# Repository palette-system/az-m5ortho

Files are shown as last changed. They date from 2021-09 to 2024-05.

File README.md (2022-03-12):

# AZ-M5ortho

## 販売サイト

- [BOOTH](https://booth.pm/ja/items/3329196)
- [遊舎工房](https://shop.yushakobo.jp/collections/keyboard/products/2949)

## メディア

【記事】AKIBA PC Hotline 様<br>
https://akiba-pc.watch.impress.co.jp/docs/news/news/1359054.html
<br><br>

【記事】fabcross 様<br>
https://fabcross.jp/news/2021/20211019_yusyakobo_m5stackkeyboard_azm5ortho.html
<br><br>

【記事】kuriharaのブログ 様<br>
https://kurihara.hatenadiary.jp/entry/2021/10/16/202059
<br><br>

【記事】ErgoMechKeyboards 様<br>
https://www.reddit.com/r/ErgoMechKeyboards/comments/qkbzg8/azm5ortho_wireless_ortho_touchpad_in_the_middle/
<br><br>

【記事】protopedia 投稿記事<br>
https://protopedia.net/prototype/2487
<br><br>

【記事】M5Stack Japan Creativity Contest 2021<br>
https://protopedia.net/event/22
<br><br>

【記事】いとうひよこ 様<br>
https://note.com/tsubuan_145/n/n36ca745d76a6
<br><br>

## ドキュメント
  
- [入っている物](/docs/azm5ortho/builtin_parts/)
- [作成マニュアル](/docs/azm5ortho/build_guide/)
- [初期設定マニュアル](/docs/azm5ortho/Initial_setting/)
- [液晶画面設定メニュー](/docs/azm5ortho/moniter_setting/)
- [WiFi設定メニュー](/docs/wifi_setting/)
- [REMAP設定](/docs/azm5ortho/remap_setting/)
- [M5StackCore2 を購入時の状態に戻す](https://w-tori.net/wp/m5stack-core2-reset/)
<br><br>

## デフォルトキーマップ

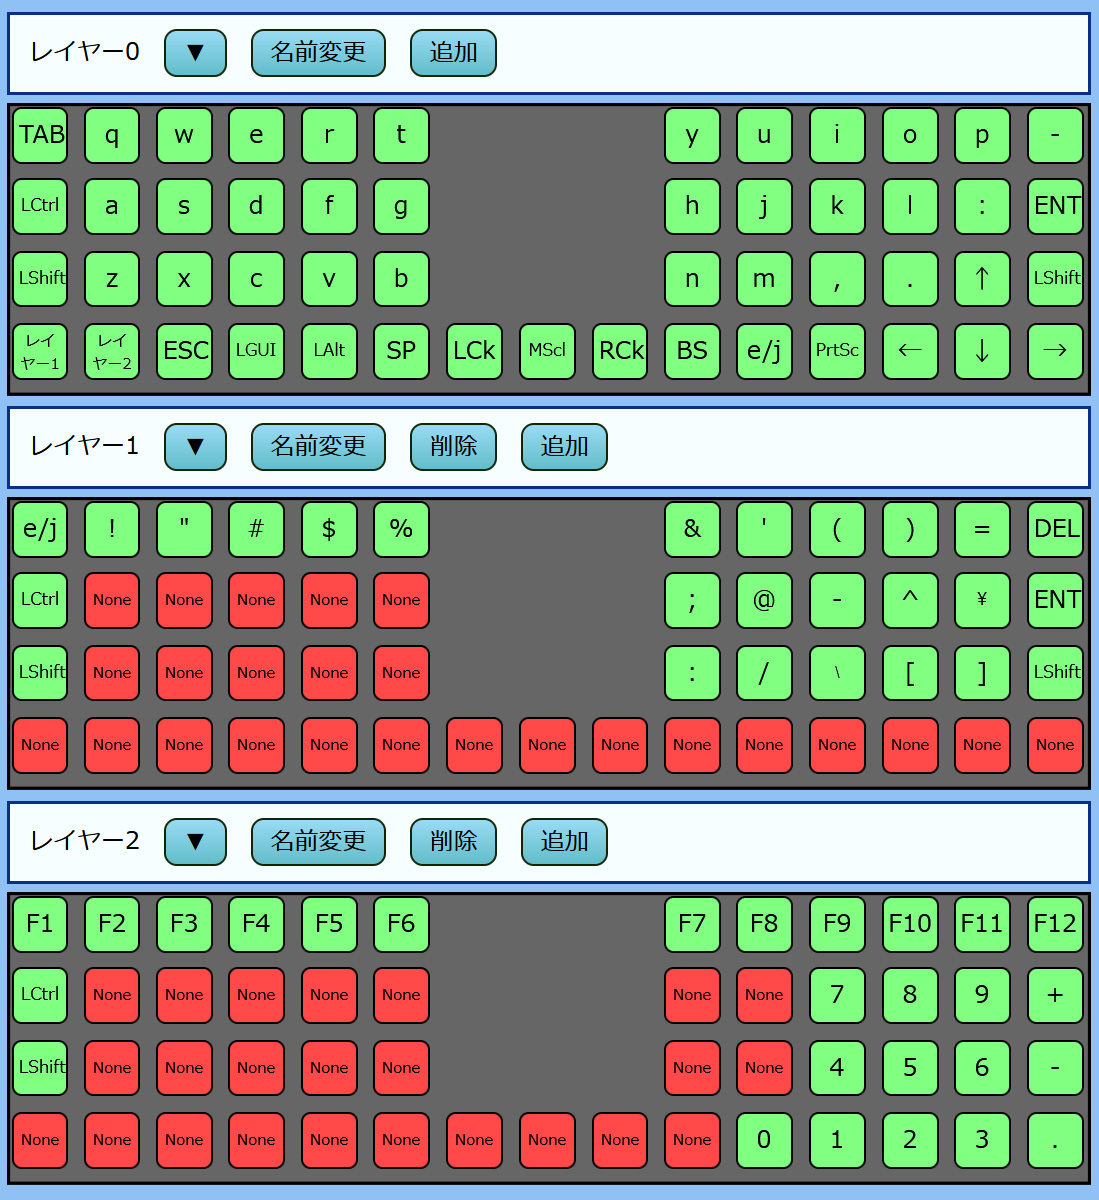
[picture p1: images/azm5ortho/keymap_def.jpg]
デフォルトキーマップ


## M5Stack Japan Creativity Contest 2021 3位入賞

[M5Stack Japan Creativity Contest 2021](https://protopedia.net/event/22)

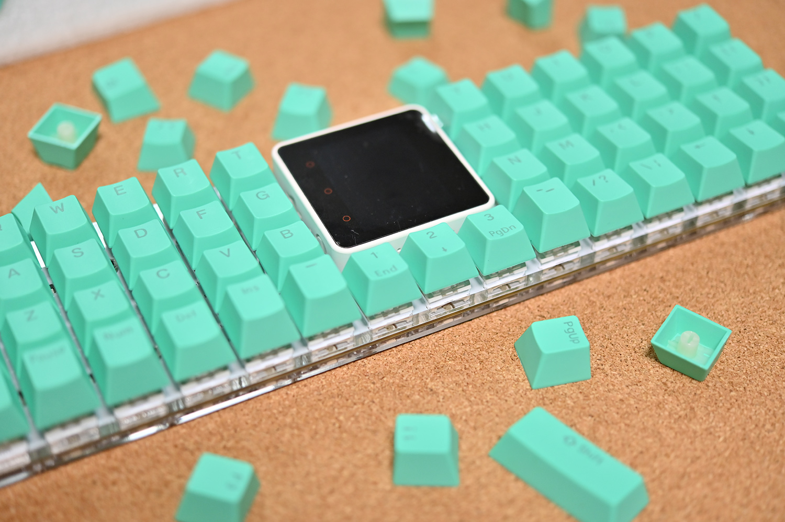
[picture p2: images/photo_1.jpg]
写真1

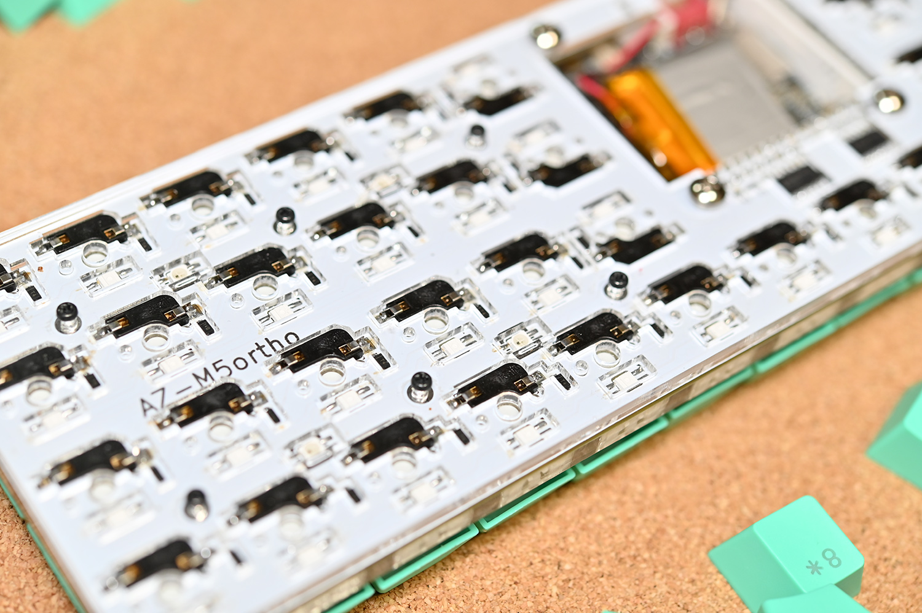
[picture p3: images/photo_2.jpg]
写真2

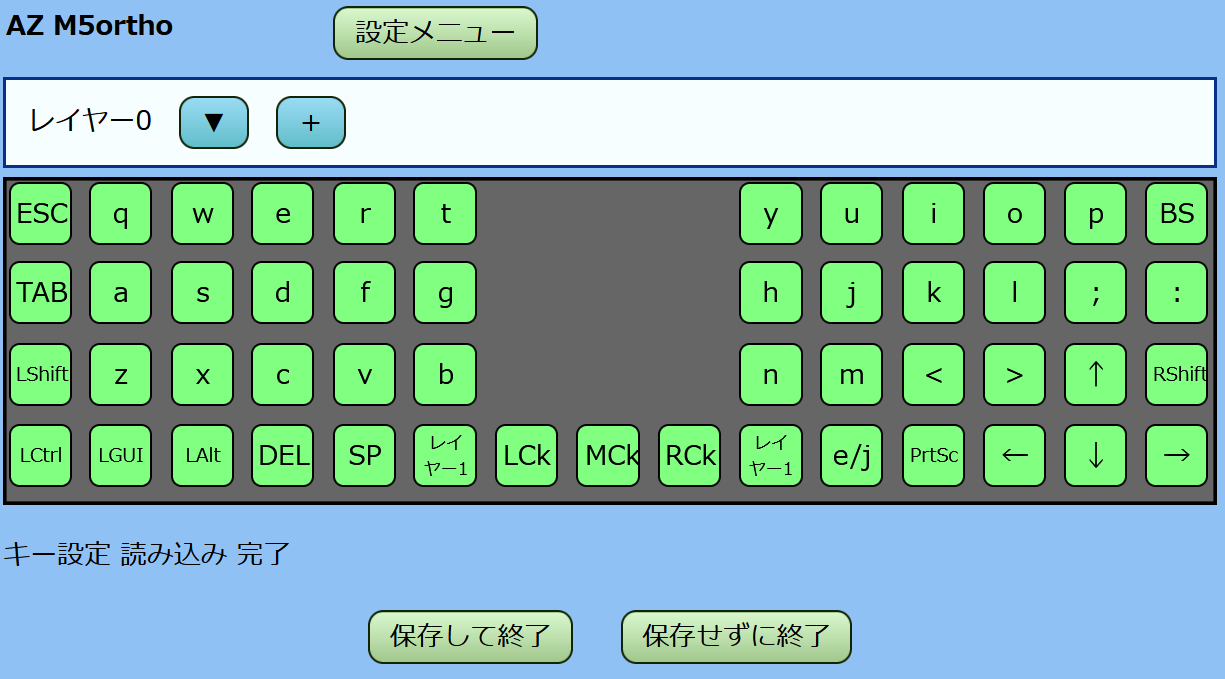
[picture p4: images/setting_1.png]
写真3

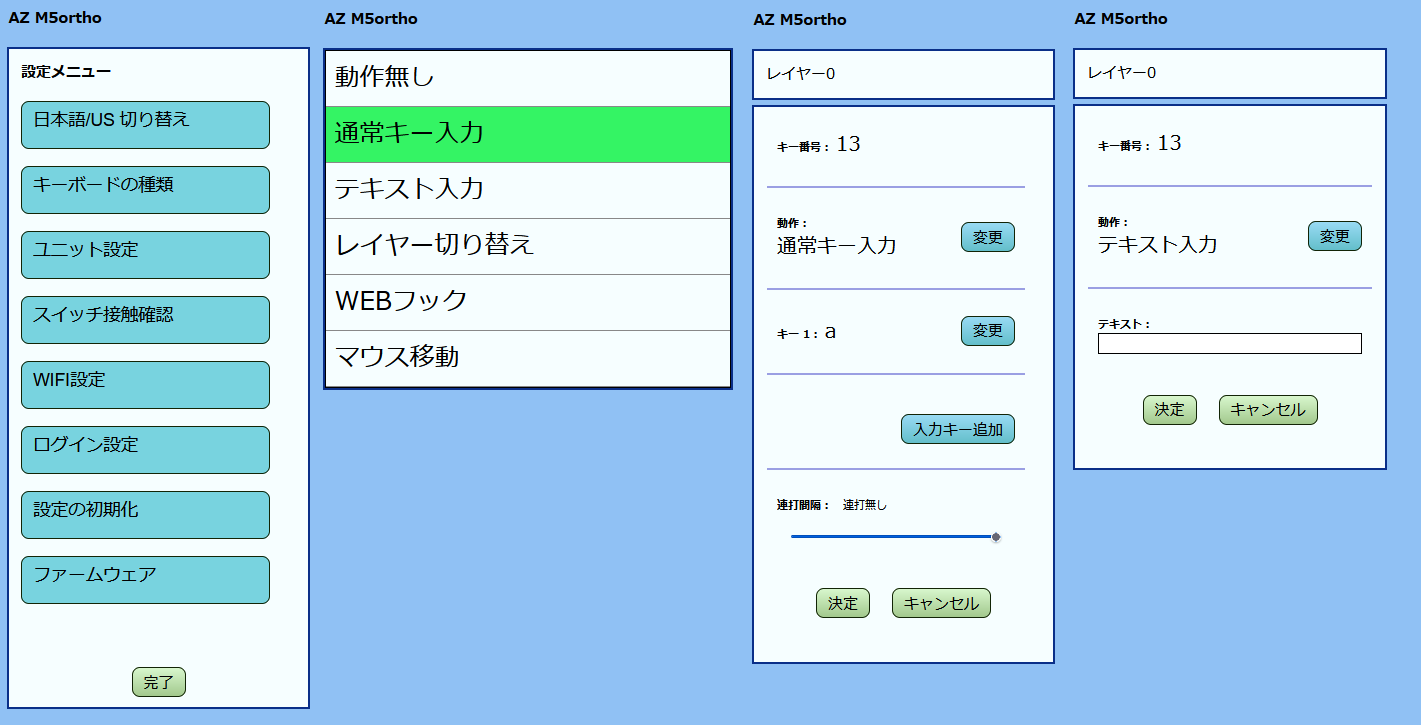
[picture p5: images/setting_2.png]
写真4

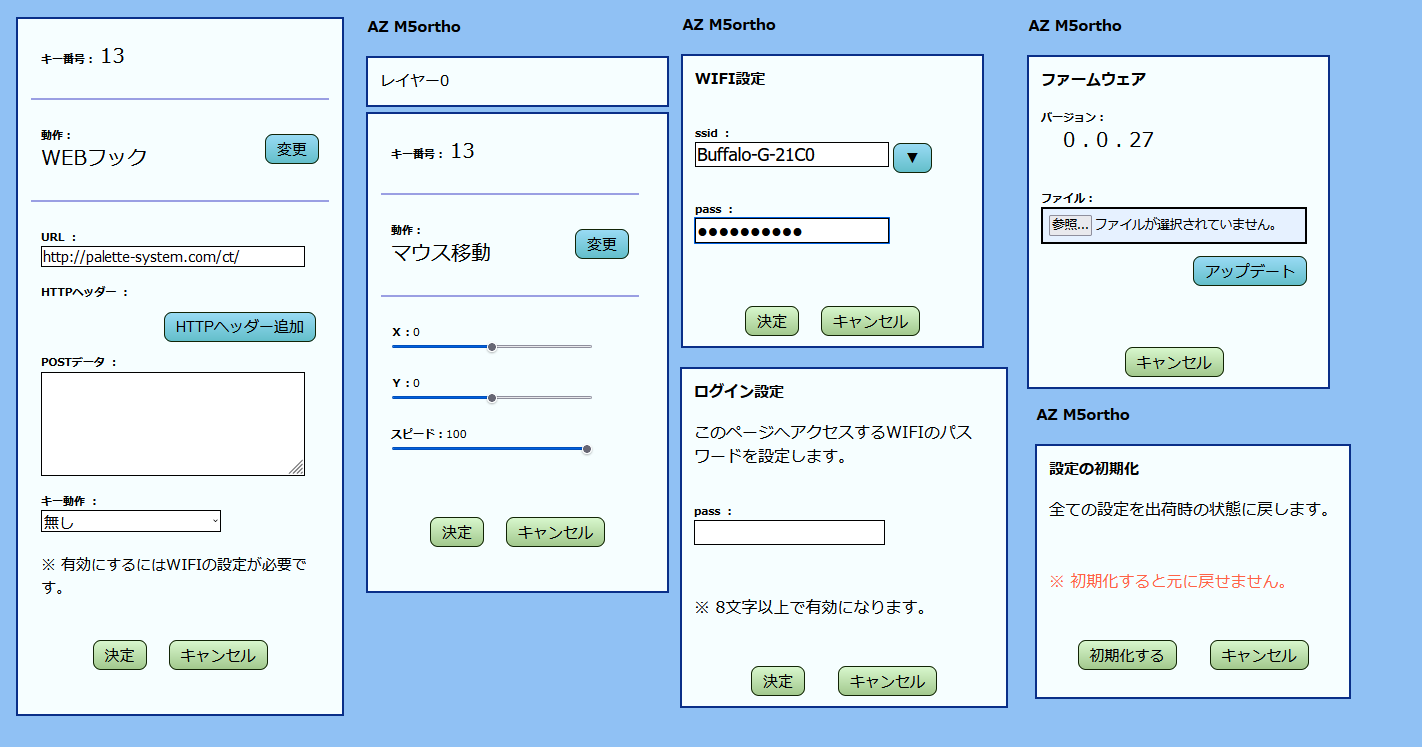
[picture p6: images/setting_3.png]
写真5


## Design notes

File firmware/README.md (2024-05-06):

# AZ-M5ortho ファームウェア
AZ-M5ortho で使用しているファームウェアソースです。<br>
こちらのソースは個人で利用する場合には自由にご利用いただいて大丈夫です。<br>
二次配布については非営利であれば著作権表示をして頂ければご利用して頂いて大丈夫です。<br>

<br><br>

ライセンス：　CC BY-NC-SA 4.0

<br><br>

## 対応商品

- えむごっち
- AZ-M5ortho

## 開発環境

- Arduino 2.3.2

　インストール手順<br>
　https://raspberrypi.mongonta.com/howto-start-m5stack-core2arduinoide/

■ボードマネージャー
- M5Stack 2.1.1

■ライブラリ
- M5Core2 0.1.9
- ESP_OTA 0.2.0
- NimBLE-Arduino 1.4.1
- ArduinoJson 7.0.4
- lv_arduino 3.0.1
- Adafruit NeoPixel 1.12.1
- Adafruit MCP23017 Arduino Library 2.3.2
- ESP8266Audio 1.9.7
- M5Stack 0.4.1
<br>
※ lv_arduino のライブラリインストール後 https://github.com/palette-system/az-m5ortho/tree/main/firmware/lv_arduino のファイルを インストールしたlv_arduinoのディレクトリにコピーして下さい。
<br>
※ 使用フォント　http://www.fontna.com/blog/1226/
<br>　　　LogoTypeGothic ロゴたいぷゴシック 07LogoTypeGothic7.ttf
<br>
※ フォントコンバーター： https://lvgl.io/tools/fontconverter
<br>
※ コンバート時に指定した文字： https://github.com/palette-system/az-m5ortho/blob/main/firmware/lv_arduino/enable_text.txt
<br><br>

## 書込み時のボード設定

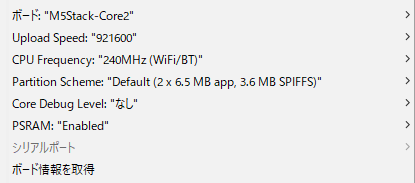
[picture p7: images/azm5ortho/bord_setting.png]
ボード設定


## こちらのツールを使用させて頂いています

- [PROGMEM作蔵さん](https://hello-world.blog.ss-blog.jp/2016-10-16)

## こちらの素材を使用させて頂いています

- [効果音ラボ](https://soundeffect-lab.info/)

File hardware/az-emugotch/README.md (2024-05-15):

# えむごっち

## PCBデータ
[PCBデータ](/hardware/az-emugotch/kicad/)

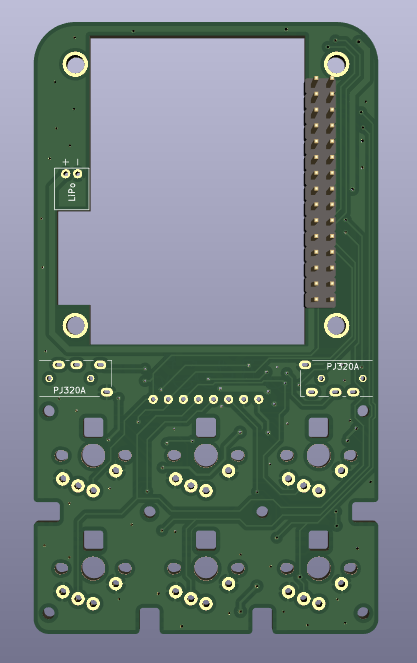
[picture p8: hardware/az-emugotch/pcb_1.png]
表

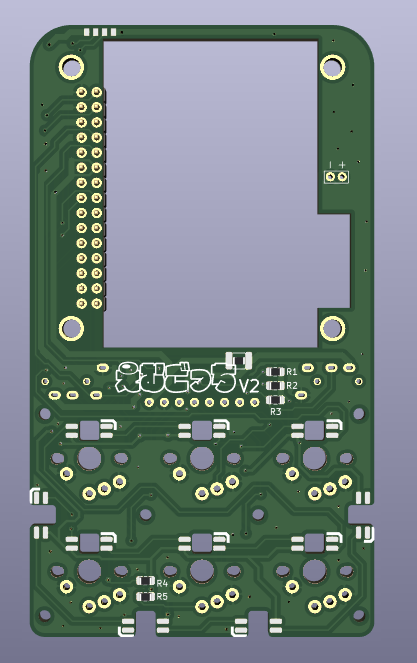
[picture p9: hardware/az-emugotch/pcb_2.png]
裏


## プレートデータ
[プレートデータ](/hardware/az-emugotch/plate/)

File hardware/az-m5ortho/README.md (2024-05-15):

# AZ-M5ortho 

## PCBデータ
[PCBデータ](/hardware/az-m5ortho/kicad/)

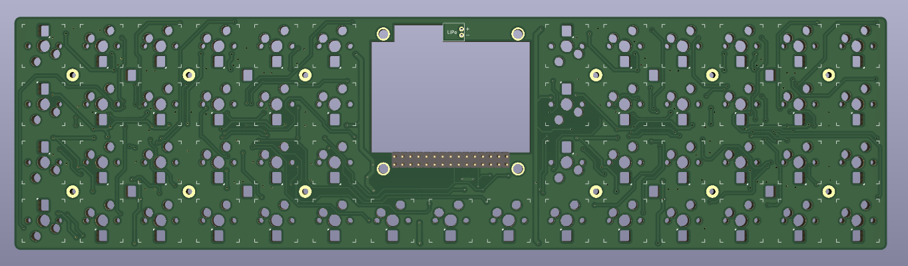
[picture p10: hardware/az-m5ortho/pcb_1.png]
表

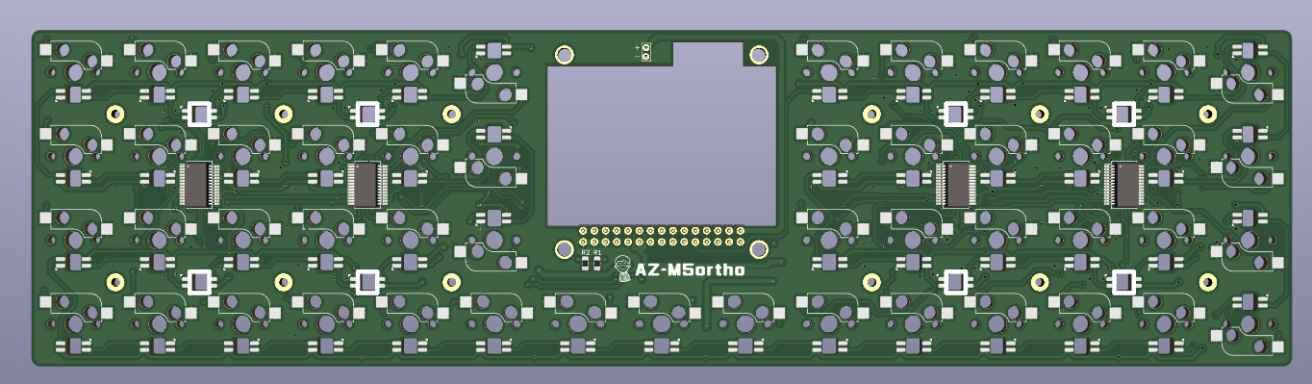
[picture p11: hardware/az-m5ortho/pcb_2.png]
裏


## プレートデータ
[プレートデータ](/hardware/az-m5ortho/plate/)

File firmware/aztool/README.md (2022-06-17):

# 設定ツール

使い方

- M5StackCore2のドライバ　CP2104 Driver　のインストール

　　　　https://shop.m5stack.com/pages/download

- このリポジトリをクローンする

- このディレクトリにある　writer.html　を Chrome で開いて　M5StackCore2　にツール対応のファームウェアを書き込む

　　　※　M5StackCore2とはUSBで接続する

- M5StackCore2とBluetoothのペアリングをする

　　　※　ペアリング済みだった人はペアリング設定を削除してもう一度ペアリングしなおす

- https://palette-system.github.io/aztool/ 　を　Chrome　で開いて設定ツールを使う

# オプションを追加する流れ

- M5StackCore2の電源が入ってない状態でオプションになる基板をTRRSで接続する

- M5StackCore2の電源を入れる

- 設定ツールを開いて「オプション設定」→「オプション追加」からオプションを追加する

- 追加が終わるとM5StackCore2の再起動をして設定画面から追い出されるので、再起動が終わったらまた設定画面から接続する。

　　※　再接続する時は一度ページをリロードした方が安全（なんか前のキャッシュが残ってたりしてて時々変な動きする時がある）

- 「キーマップ設定」を開くと登録したオプションが表示されていて、キー設定が出来る

- キー設定が終わったら「保存して再起動」すると設定した内容が保存されて使えるようになってる

# おまけ

「設定JSON編集」で設定に使用しているJSONを直接操作できる。

VID/PID、I2Cのピン、キーボードのピンなどキーボードで設定してる内容はだいたいこのJSONで設定してます。

| キー | 内容 |
| --- | --- |
| ap.pass | 設定モード(WIFI)で起動した時のWIFIに接続するパスワード |
| wifi | M5StackCore2がWIFIにアクセスするためのAPとパスワード |
| vendorId<br>productId | ベンダーID<br>プロジェクトID |
| rgb_pin<br>rgb_len | NeoPixcell へ接続してるピン<br>何個接続してるか |
| led_num<br>key_matrix<br>matrix_row<br>matrix_col | NeoPixcell 表示に使う用の設定 |
| disp_rotation | 画面の向き |
| keyboard_name | キーボード名 |
| keyboard_type | キーボードの種類コード<br>この値で今どのキーボードとして動いてるか判定 |
| keyboard_pin | 本体のキースイッチに設定しているピン<br>direct - GPIOから直にスイッチ<br>touch - 未使用<br>ioxp - エキスパンダのアドレス(全てdirect) |
| ioxp_pin | I2C接続するピン |
| default_layer | キーボード起動時のレイヤーの番号 |
| layers | キー入力の設定、キー名がレイヤーID |
| layers[n].name | レイヤーの名前 |
| layers[n].keys | レイヤーに登録されているキー設定<br>キー名がキーのID |
| layers[n].keys[k].press | キーが押された時の動作 |
| layers[n].keys[k].press.action_type | 動作のタイプ |
| layers[n].keys[k].press.key | 送信するHIDコード(５個まで同時押し可) |
| option_set | 付けているオプション設定(AZ-Macro用) |
| i2c_option | 設定したI2Cオプションの設定 |
| i2c_option[n].id | オプションの識別番号 |
| i2c_option[n].type | オプションの種類<br>今は 1:エキスパンダ のみ |
| i2c_option[n].enable | オプションが有効かどうか（無効だと入力しても反応しない） |
| i2c_option[n].ioxp | オプションで使用するエキスパンダ(複数)<br>と、エキスパンダのピン設定 |
| i2c_option[n].map_start | キー設定のIDとマッピング開始する番号 |
| i2c_option[n].map | エキスパンダの入力データの何番目がキーになるかのマッピング |
| layout | キーマップ設定でキー配列をドラッグで移動した表示位置 |

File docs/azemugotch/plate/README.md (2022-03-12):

# えむごっち プレートデータ

このディレクトリにあるデータがえむごっちで利用するアクリルプレートのデータです。

- emugotch_middle (3mm)
- emugotch_pcb_bottom (2mm)
- emugotch_pcb_top (5mm)
- emugotch_top_and_bottom (3mm)

# ライセンス

## 使用許諾

- 個人利用に限り自由に使用して頂いて構わないです。

## 再許諾

- このデータを加工して作成したデータも、こちらのライセンスを継承していれば公開しても構わないです。
- 公開時はパレットシステムの名前とこのページへのリンクをどこかへ表記する事。

## 禁止事項

- このデータを使用して作成したいかなる物でも(物理、データ問わず)利用して利益を得てはならない。
- このデータを加工して他の著作権物を侵害するデータの作成、および配布を禁止します。

## 保証及び責任の制限

- このデータを利用して発生したいかなる損害においても損害賠償責任を負いません。

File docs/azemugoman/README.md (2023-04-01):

# えむごまん

## 入っている物

- えむごまん基板　×　１
- バッテリー用PHコネクタ　×　１
- TRRSジャック　×　２
- 六角レンチ　×　１
- ピンヘッダ(2×20)　×　１
- RGBLED　×　１０
- 基板固定用M2×8ｍｍネジ　×　４
- えむごまんボディ　×　１

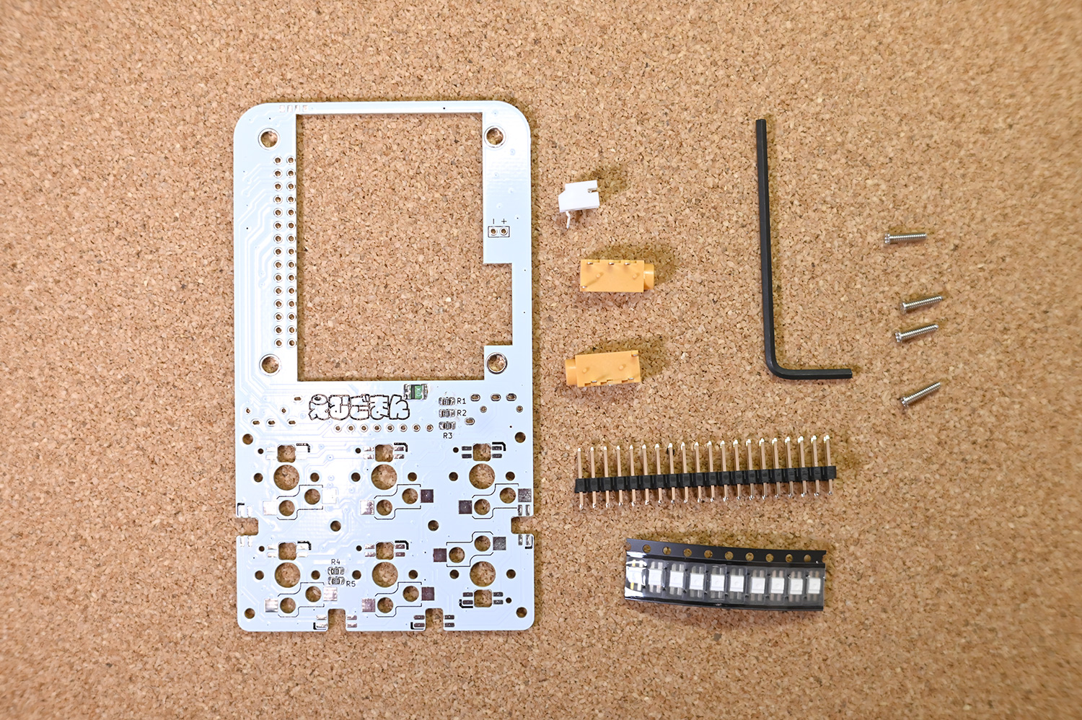
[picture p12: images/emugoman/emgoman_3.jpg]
build_parts

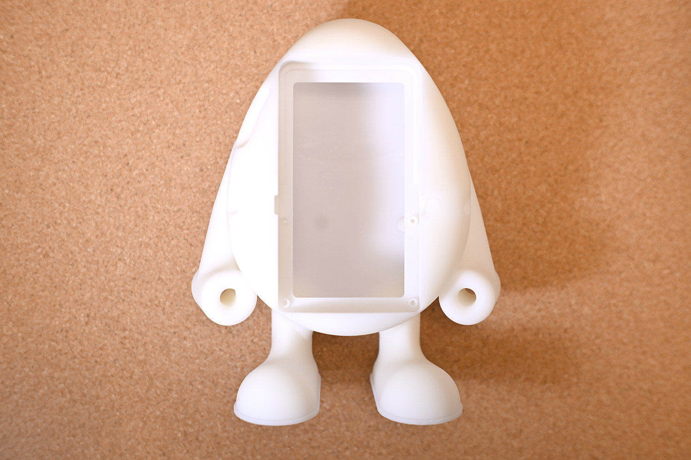
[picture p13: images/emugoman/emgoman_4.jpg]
build_body


## 別途必要

- M5StackCore2　×　１
- Chocソケット　×　６
- Chocスイッチ　×　６（V1、V2両方対応）
- キーキャップ　×　６

## 組み立て手順

はんだ付けやファームウェアの書き込みはえむごっちのマニュアルを参考にして下さい。

<a href="/docs/azemugotch/build_guide">えむごっち　組み立て方</a><br>
<a href="/docs/azm5ortho/Initial_setting">えむごっち　ファームウェア書込み</a><br>

参考用写真

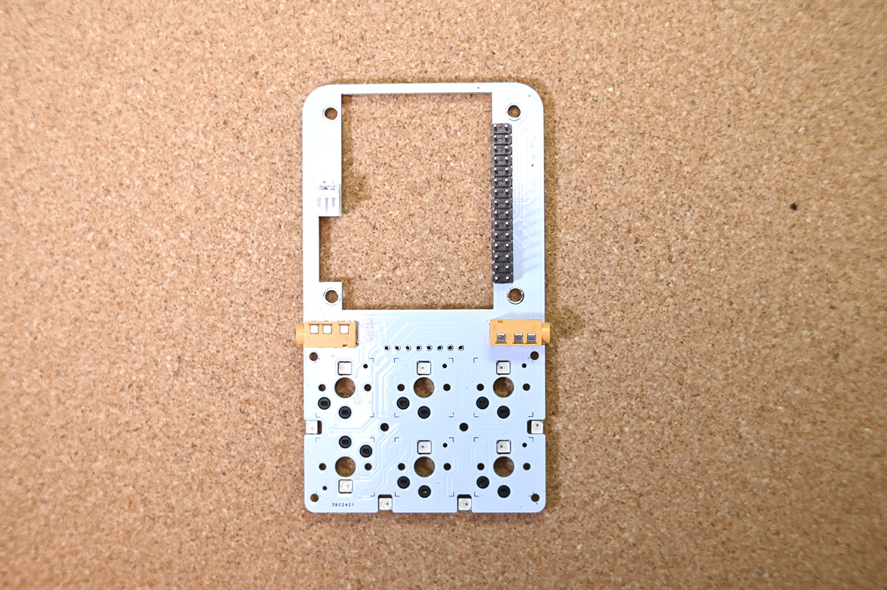
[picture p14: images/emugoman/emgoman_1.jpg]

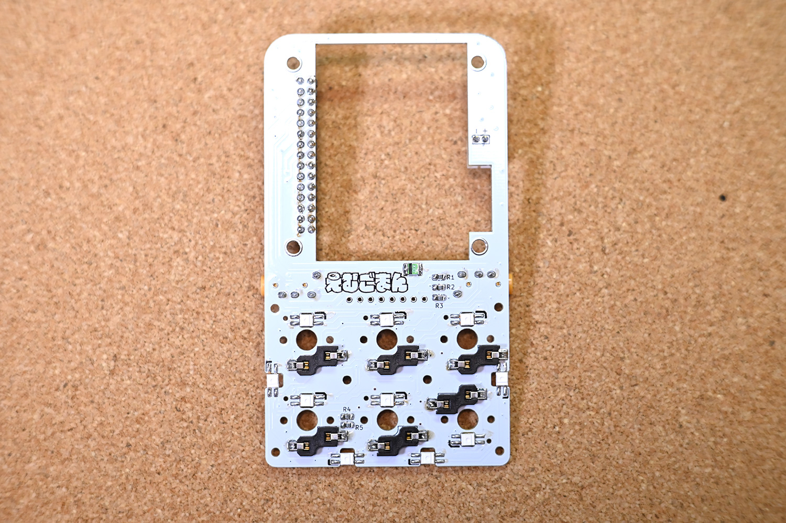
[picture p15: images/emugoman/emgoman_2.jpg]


はんだ付けが完了したらM2ネジ4本を使用してえむごまんボディに基板を固定して、スイッチをはめ込んで下さい。

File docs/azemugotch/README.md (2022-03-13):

# えむごっち

## 販売サイト

- [BOOTH](https://booth.pm/ja/items/3696255)

## メディア

【記事】へりかる 様<br>
https://helical-engineer.com/keyboard-emugotch/
<br><br>

## ドキュメント
  
- [入っている物](/docs/azemugotch/builtin_parts/)
- [作成マニュアル](/docs/azemugotch/build_guide/)
- [初期設定マニュアル](/docs/azm5ortho/Initial_setting/)
- [液晶画面設定メニュー](/docs/azm5ortho/moniter_setting/)
- [WiFi設定メニュー](/docs/wifi_setting/)
- [登録用のWAVファイル作成方法](/docs/azemugotch/create_wav/)
- [回路図](/images/emugotch/emugotch_kairo.png)
- [ファームウェア](/firmware/)
- [アクリルプレートのデータ](/docs/azemugotch/plate/)
- [M5StackCore2 を購入時の状態に戻す](https://w-tori.net/wp/m5stack-core2-reset/)
<br><br>

## 説明

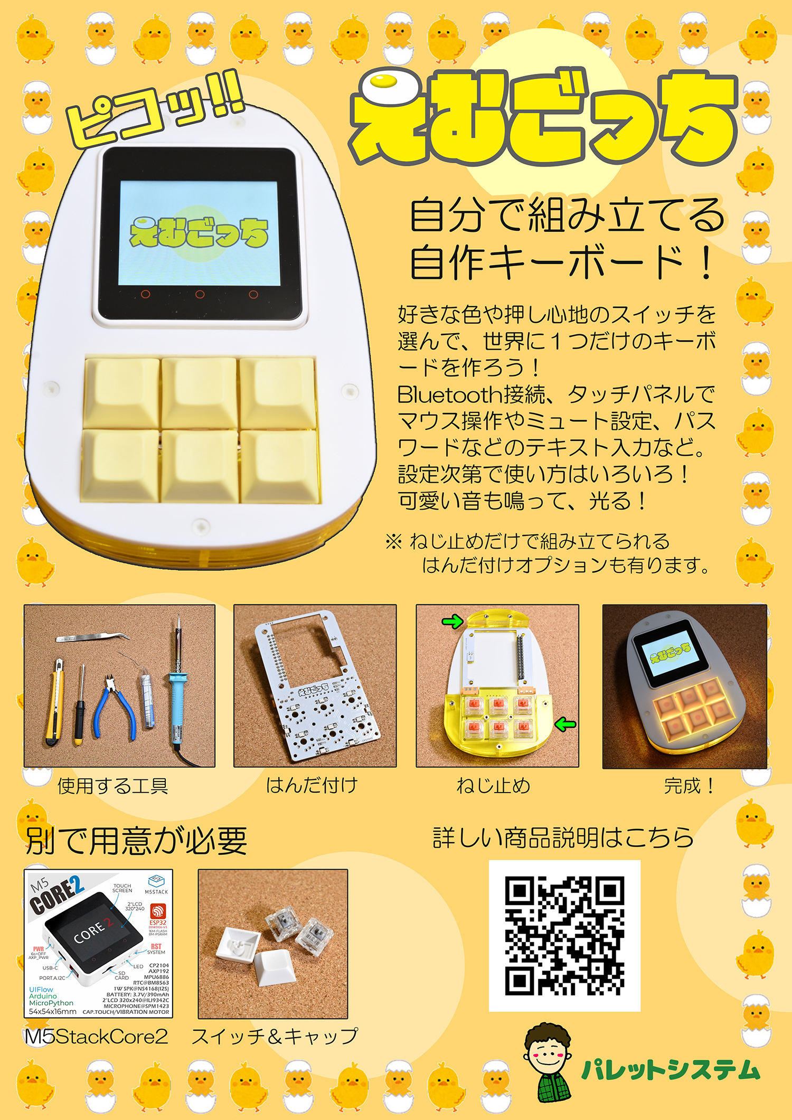
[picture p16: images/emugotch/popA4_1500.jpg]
pop

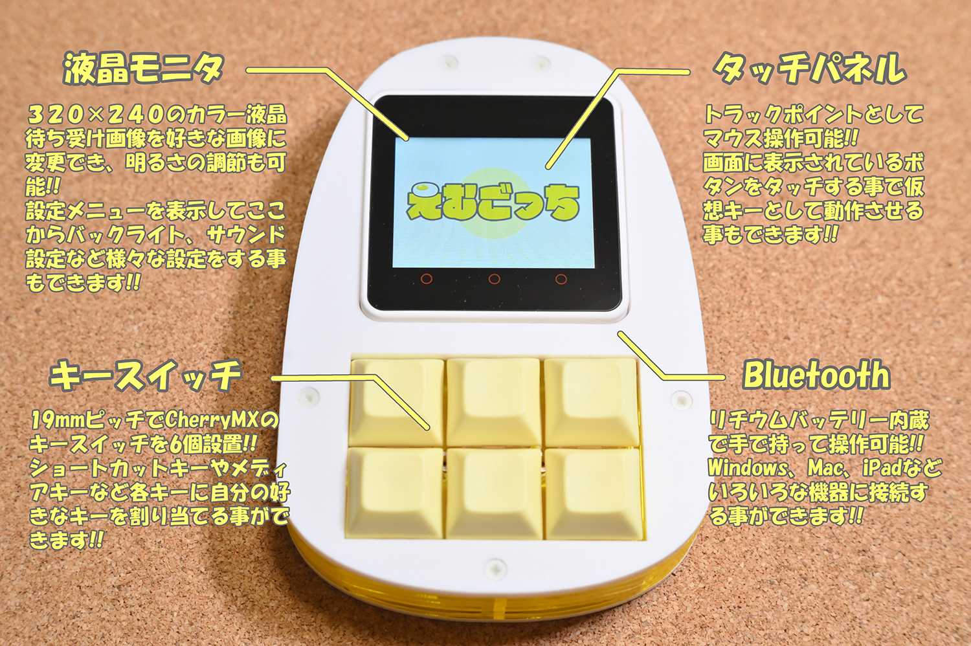
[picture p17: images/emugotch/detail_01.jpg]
説明1

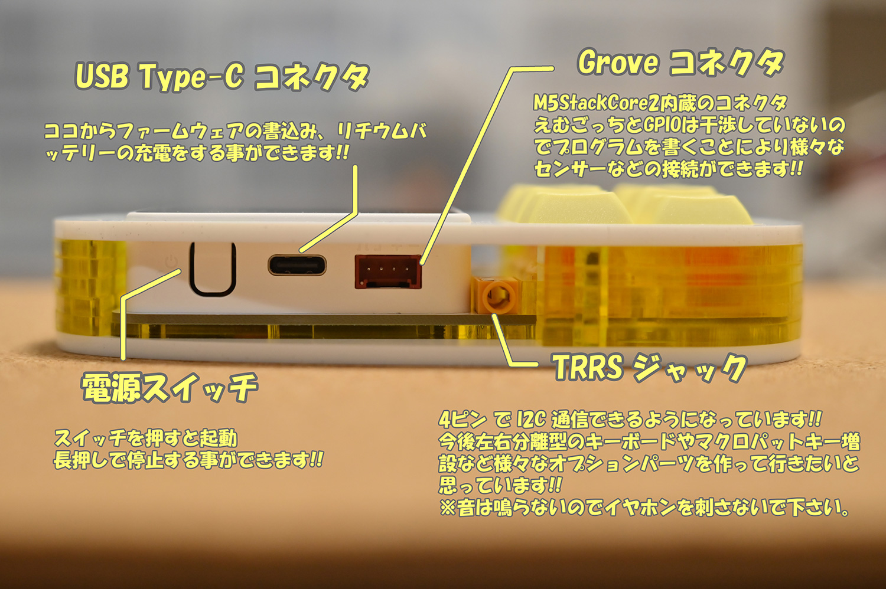
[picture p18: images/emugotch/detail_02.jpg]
説明2

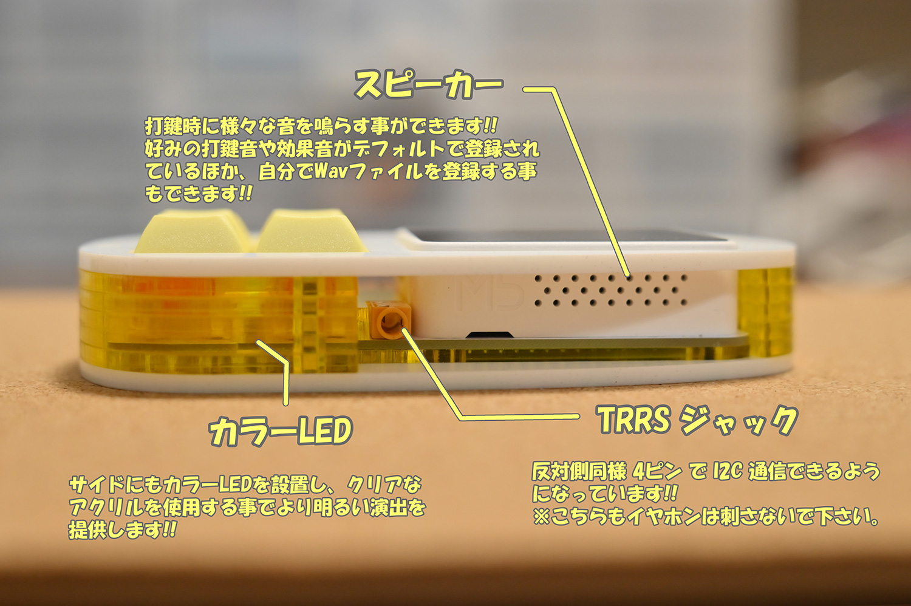
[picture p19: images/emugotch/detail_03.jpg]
説明3


## 写真

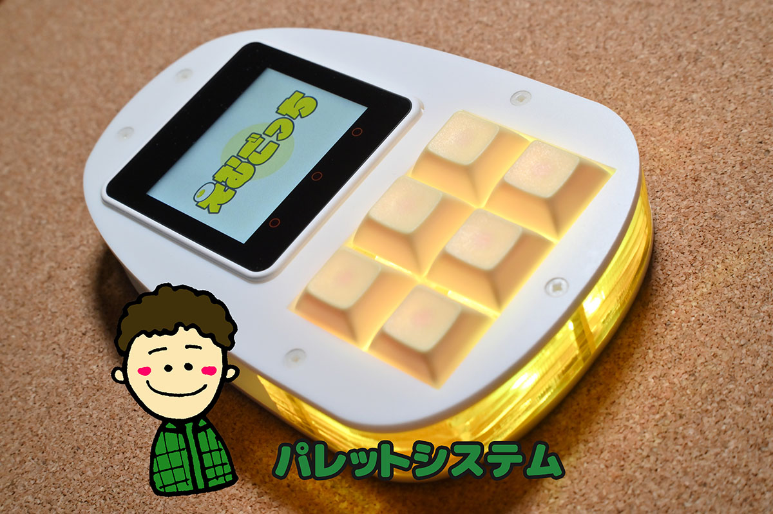
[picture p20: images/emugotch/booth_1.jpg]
写真1

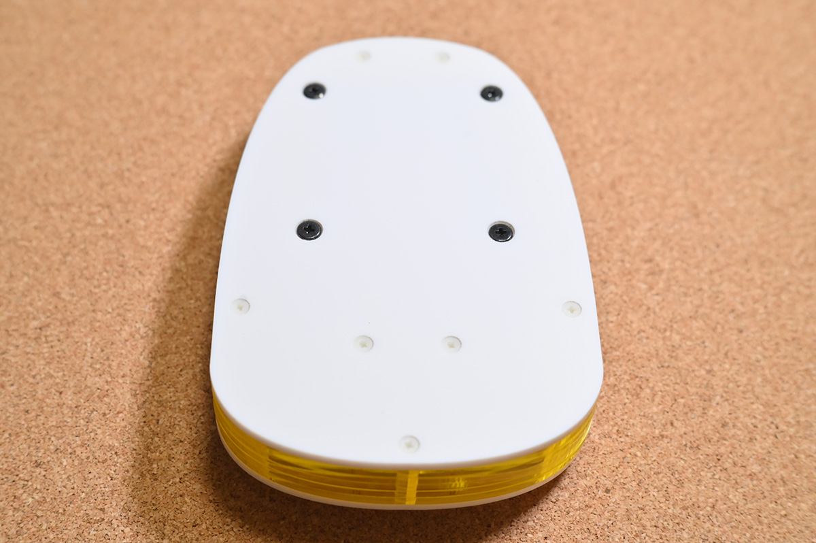
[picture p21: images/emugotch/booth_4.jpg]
写真2

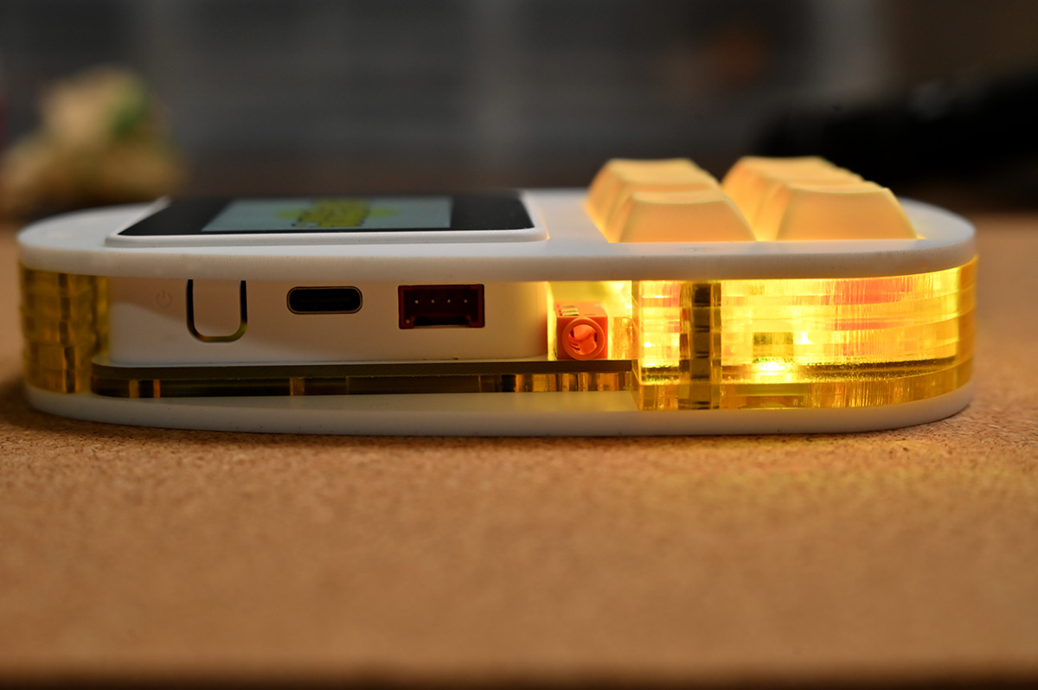
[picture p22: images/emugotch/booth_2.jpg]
写真3

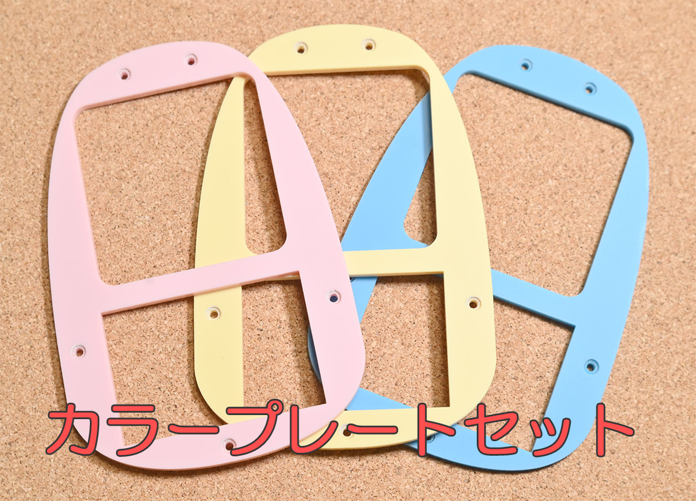
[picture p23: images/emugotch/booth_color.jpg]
写真4

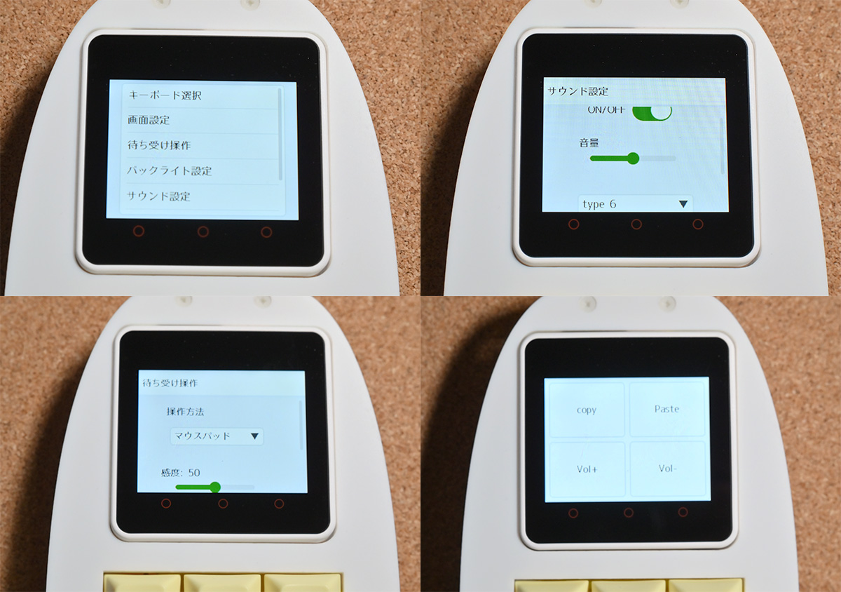
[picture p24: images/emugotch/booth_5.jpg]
写真5

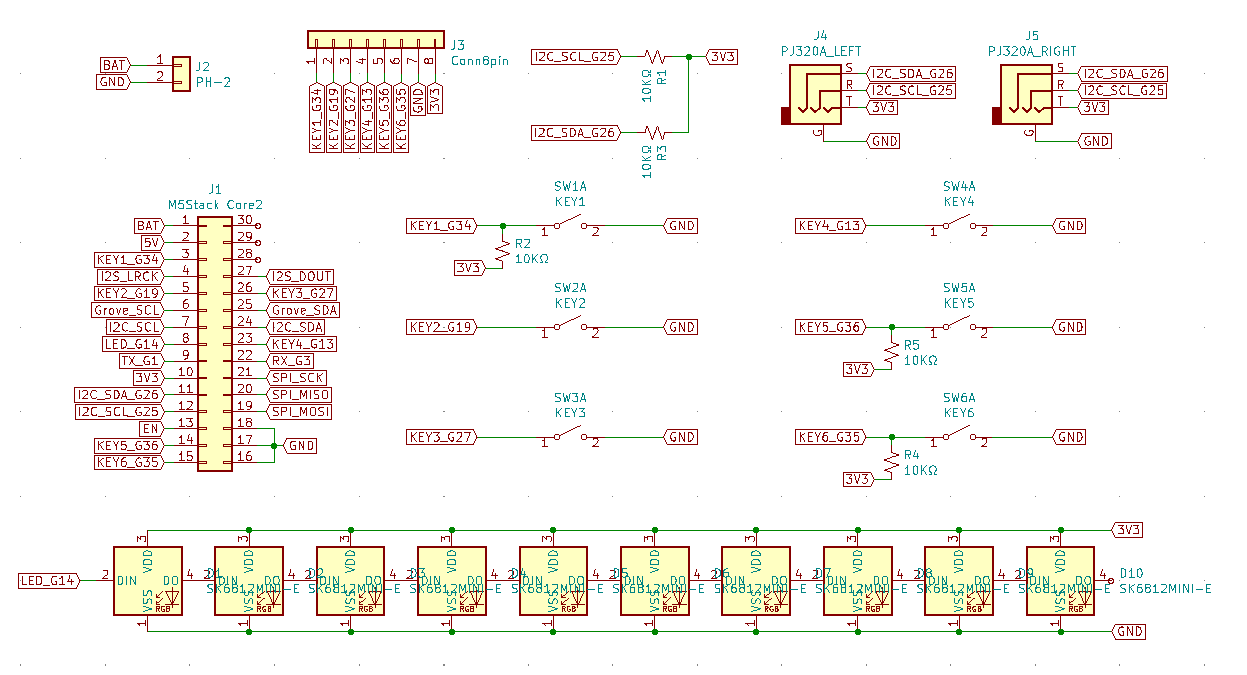
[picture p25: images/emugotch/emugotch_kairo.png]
写真6


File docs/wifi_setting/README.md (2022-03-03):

# Wifi 設定メニュー

<br><br>

## 設定画面の開き方
<table>
  <tr>
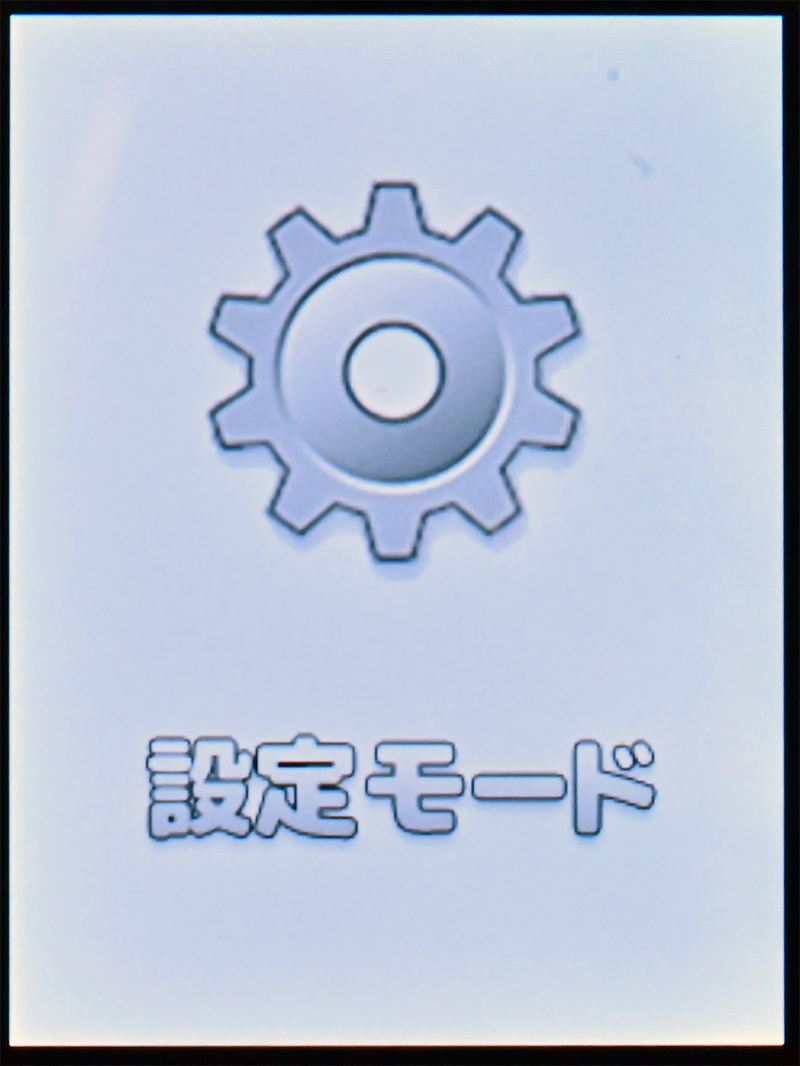
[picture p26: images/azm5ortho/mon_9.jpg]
    <td></td>
    <td valign="top">
      キーボードを設定モードで再起動します。<br>
      設定モードでの再起動の方法はこちら<br>
       → <a href="https://github.com/palette-system/az-m5ortho/tree/main/docs/azm5ortho/moniter_setting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" target="_blank">https://github.com/palette-system/az-m5ortho/tree/main/docs/azm5ortho/moniter_setting/</a>
    </td>
  </tr>
  <tr>
    <td></td>
    <td valign="top">
      この状態でPCやスマートフォンからWiFiのアクセスポイントを検索すると「<b>AZ-Keyboard-****</b>」があるので接続します。
    </td>
  </tr>
  <tr>
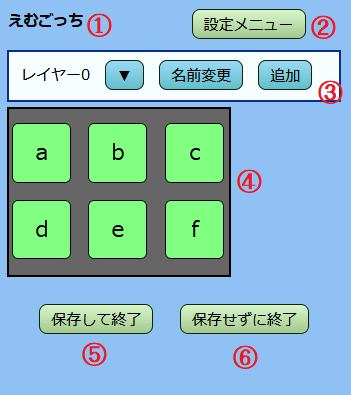
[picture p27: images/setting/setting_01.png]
    <td></td>
    <td valign="top">
      WiFiに接続できるとブラウザが立ち上がり、自動的に設定画面が開きます。
    </td>
  </tr>
</table>

<br><br>

## メイン画面と キー設定画面の説明
<table>
  <tr>
    <td></td>
    <td valign="top">
      <b>メイン画面</b><br><br>
      １．現在編集しているキーボードの名前が表示されます。<br>
      <br>
      ２．設定メニューを開きます。詳細については設定メニューの説明に記述します。<br>
      <br>
      ３．現在選択しているレイヤーが表示されます。<br>
      　▼　→　選択しているレイヤーを切り替えられます。<br>
      　名前変更　→　レイヤーの表示名を変更できます。<br>
      　追加　→　レイヤーを追加できます。<br>
      　×　→　選択中のレイヤーを削除できます。(レイヤー０は削除できません)<br>
      <br>
      ４．現在キーに割り当てている設定が表示されます。<br>
      　キーをクリックするとキーの設定ができます。<br>
      <br>
      ５．変更したキー設定をキーボードに保存して設定モードを終了します。<br>
      <br>
      ６．変更を保存せずに設定モードを終了します。
    </td>
  </tr>
  <tr>
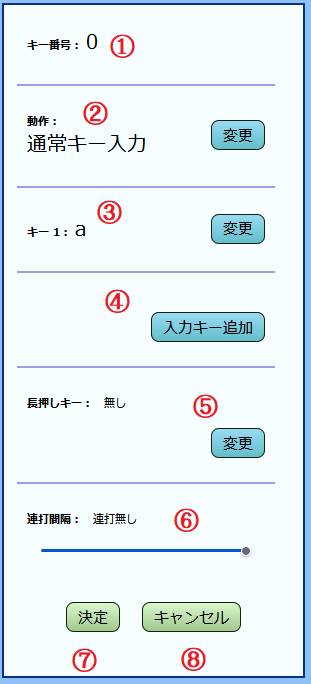
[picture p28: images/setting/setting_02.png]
    <td></td>
    <td valign="top">
      <b>通常キー入力</b><br><br>
      １．現在編集しているキーの番号が表示されます。<br>
      <br>
      ２．キーを押した時の動作が表示されます。<br>
      　<b>変更</b> をクリックすると変更できます。<br>
      <br>
      ３．入力するキーが表示されます。<br>
      　<b>変更</b> をクリックすると変更できます。<br>
      　<b>×</b> をクリックすると削除できます。<br>
      <br>
      ４．入力するキーを増やせます。最大5キーまで増やせます。<br>
      <br>
      ５．長押しのモディファイアを設定できます。<br>
      　長押ししている間ここで登録したモディファイアが押され、短押しされた時③④で設定したキーが入力されます。<br>
      <br>
      ６．連打入力を設定できます。押している間③④で登録したキーを連打します。<br>
      　スライドが左に行くほど連打の周期が早くなります。<br>
      　スライドを一番右に持って行くと連打無しです。<br>
      <br>
      ７．設定した内容をキーに登録します。<br>
      <br>
      ８．設定内容を登録せずにメイン画面に戻ります。<br>
    </td>
  </tr>
  <tr>
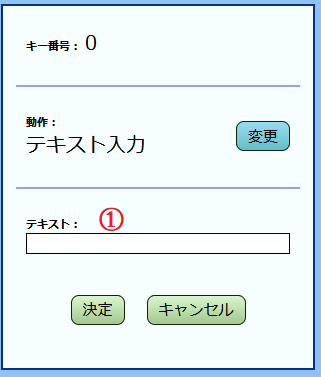
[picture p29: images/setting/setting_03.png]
    <td></td>
    <td valign="top">
      <b>テキスト入力</b><br><br>
      １．入力させたいテキストを登録できます。<br>
      　半角英数字、記号のみで全角文字は登録できません。<br>
    </td>
  </tr>
  <tr>
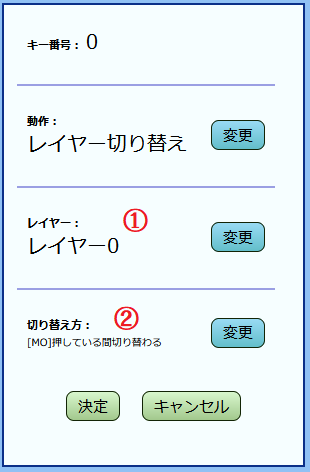
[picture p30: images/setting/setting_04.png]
    <td></td>
    <td valign="top">
      <b>レイヤー切り替え</b><br><br>
      １．キーを押した時に切り替えたいレイヤーを設定します。<br>
      　<b>変更</b> をクリックすると変更できます。<br>
      <br>
      ２．切り替え方を選択できます。<br>
      　<b>[TO]</b>　切り替え後デフォルトになる<br>
      　<b>[MO]</b>　押している間切り替わる<br>
      　<b>[DF]</b>　切り替え後デフォルトになる<br>
      　<b>[TG]</b>　切り替わったままになる<br>
      　<b>[OSL]</b>　非対応<br>
      　<b>[TT]</b>　非対応<br>
    </td>
  </tr>
  <tr>
    <td></td>
    <td valign="top">
      <b>WEBフック入力</b><br><br>
      キーを押した時にHTTPリクエストを送信します。<br><br>
      １．開くページの URL を設定できます。<br>
      <br>
      ２．HTTPリクエストヘッダーを追加する事ができます。複数指定できます。<br>
      　<b>HTTP ヘッダー追加</b> ヘッダーを新しく追加できます。<br>
      　<b>編集</b> ヘッダーを編集できます。<br>
      　<b>削除</b> ヘッダーを削除できます。<br>
      <br>
      ３．POST で任意のデータを送信できます。<br>
      　キーバリュー、JSON など自分でフォーマットして指定して下さい。<br>
      　この欄を空にすると GET リクエストになります。<br>
      <br>
      ４．HTTP 取得した後のキー動作を下記から指定できます。<br>
      　動作無し<br>
      　結果のステータスコードをキー入力<br>
      　HTTP レスポンスをキー入力<br>
      <br><br><br>
      ※ WIFI 設定がしてある必要があります。
      ※ HTTP レスポンスは 1024 バイトまで取得します。
      ※ HTTP レスポンス内に全角文字が含まれていると入力動作が不安定になります。
    </td>
  </tr>
  <tr>
    <td></td>
    <td valign="top">
      <b>マウス移動</b><br><br>
      キーを押している間マウスを移動します。<br><br>
      １．横移動する距離を設定します。<br>
      　マイナスを指定すると左、プラスを指定すると右に移動します。<br>
      <br>
      ２．縦移動する距離を設定します。<br>
      　マイナスを指定すると上、プラスを指定すると下に移動します。<br>
      <br>
      ３．移動する速度を設定します。数値が高いほど早く動きます<br>
    </td>
  </tr>
</table>

<br><br>

## 設定メニュー画面
<table>
  <tr>
    <td></td>
    <td valign="top">
      <b>設定メニュー</b><br><br>
      <b>ソフトウェアキー</b><br>
      　M5StackCore2画面に表示する仮想キーの設定をします。<br>
      <br>
      <b>日本語/US 切り替え</b><br>
      　HID送信するキーコードのタイプを変更します。<br>
      <br>
      <b>キーボードの種類</b><br>
      　M5StackCore2に接続しているキーボードの種類を確認できます。<br>
      <br>
      <b>モニタ設定</b><br>
      　M5StackCore2画面に表示する待ち受け画像などの設定をします。<br>
      <br>
      <b>サウンド設定</b><br>
      　打鍵した時に再生するWAVファイルの登録ができます。<br>
      <br>
      <b>ユニット設定</b><br>
      　準備中です。<br>
      <br>
      <b>スイッチ接触確認</b><br>
      　キーが押されているかチェックできます。<br>
      <br>
      <b>WIFI設定</b><br>
      　M5StackCore2をWifiに接続するためのSSID,PASSの設定をします。<br>
      <br>
      <b>ログイン設定</b><br>
      　この管理ページへログインするためのパスワードを設定します。<br>
      <br>
      <b>設定の初期化</b><br>
      　M5StackCore2に保存した設定の内容をリセットします。<br>
      <br>
      <b>ファームウェア</b><br>
      　使用しているファームウェアのバージョンを確認します。<br>
    </td>
  </tr>
  <tr>
    <td></td>
    <td valign="top">
      <b>ソフトウェアキー 画面</b><br><br>
      M5StackCore2画面に表示する仮想キーの設定をします<br>
      最大で6キーまで登録できます。<br>
      <br>
      <b>button*</b><br>
      　クリックすると設定しているボタンを押した時の動作を変更できます<br>
      <br>
      <b>削除</b><br>
      　ボタンを削除できます。<br>
      <br>
      <b>キー追加</b><br>
      　仮想キーのボタンを追加できます。<br>
    </td>
  </tr>
  <tr>
    <td></td>
    <td valign="top">
      <b>日本語/US 切り替え 画面</b><br><br>
      HID送信するキーコードのタイプを変更します<br>
      <br>
      <b>変更</b><br>
      　クリックするとタイプを変更できます<br>
    </td>
  </tr>
  <tr>
    <td></td>
    <td valign="top">
      <b>モニター設定 画面</b><br><br>
      M5StackCore2画面の設定を変更します。<br>
      <br>
      <b>待ち受け画像</b><br>
      　キーボード起動中に表示する画像を設定できます。<br>
      　ファイルはBMP、JPEG、PNGが指定できます。<br>
      　サイズは320×240(縦長時は240×320)に収まるように小さくされます。<br>
      <br>
      <b>確認</b><br>
      　選択した画像をM5StackCore2のモニタに表示します。(少し時間が掛かります)<br>
      <br>
      <b>削除</b><br>
      　設定している画像を削除します。<br>
      　何も設定されていない場合デフォルトの待ち受けが表示されます。<br>
      <br>
      <b>決定</b><br>
      　設定した画像をM5StackCore2に保存してメニューに戻ります。<br>
      <br>
      <b>キャンセル</b><br>
      　メニューに戻ります。<br>
    </td>
  </tr>
  <tr>
    <td></td>
    <td valign="top">
      <b>サウンド設定 画面</b><br><br>
      打鍵時のカスタム音の設定を変更します。<br>
      <br>
      <b>カスタム音(デフォルト)</b><br>
      　打鍵音設定に”カスタム音”を設定して打鍵した時に再生されるWAVファイルを設定します。<br>
      <br>
      <b>カスタム音(エンター)</b><br>
      　打鍵音設定に”カスタム音”を設定してエンターを押した時に再生されるWAVファイルを設定します。<br>
      <br>
      <b>決定</b><br>
      　設定したWAVファイルをM5StackCore2に保存してメニューに戻ります。<br>
      <br>
      <b>キャンセル</b><br>
      　メニューに戻ります。<br>
      <br>
      <br>
      ※ WAVファイルのビットレートは自動認識するのでお好みの音質でWAVファイルを作成して下さい。<br>
      ※ 2チャンネル入ったファイルでもモノラルで再生されます。<br>
      ※ ファイルサイズは500KBまでです。<br>
    </td>
  </tr>
  <tr>
    <td></td>
    <td valign="top">
      <b>WIFI設定 画面</b><br><br>
      キーボード本体が WIFI に接続するための設定ができます。<br>
      設定は複数設定可能で、一番電波が強いアクセスポイントに接続しに行きます。<br>
      この設定をするとキーボードモードで起動した時に WIFI に接続しに行くので起動が遅くなります。<br>
      また、WIFI に常時接続した状態なので電池の消費が早いです。<br>
      WEB フックなどを使用する予定が無い場合は設定しない事をオススメします。<br>
      <br>
      <b>編集</b><br>
      　登録した WIFI 設定を編集します。<br>
      <br>
      <b>削除</b><br>
      　登録した WIFI 設定を削除します。<br>
      <br>
      <b>WIFI 追加</b><br>
      　新しく WIFI 設定を登録します。<br>
      <br>
      <b>完了</b><br>
      　メニューに戻ります。<br>
    </td>
  </tr>
  <tr>
    <td></td>
    <td valign="top">
      <b>WIFI アクセスポイント設定 画面</b><br><br>
      <br>
      <b>ssid</b><br>
      　▼をクリックするとアクセスポイントを探して選択できます。<br>
      <br>
      <b>pass</b><br>
      　アクセスポイントにログインするためのパスワードを設定します。<br>
      <br>
      <b>決定</b><br>
      　アクセスポイントの情報を登録してWIFI設定画面に戻ります。<br>
      <br>
      <b>キャンセル</b><br>
      　WIFI設定画面に戻ります。<br>
    </td>
  </tr>
  <tr>
    <td></td>
    <td valign="top">
      <b>ログイン設定 画面</b><br><br>
      設定画面に入るための WIFI パスワードを設定します。<br>
      ここで指定したパスワードを忘れると設定画面に入れなくなるので注意して下さい。<br>
      <br>
      <b>pass</b><br>
      　ログインするためのパスワードを設定します。<br>
      <br>
      <b>決定</b><br>
      　パスワードを設定してメニューに戻ります。<br>
      <br>
      <b>キャンセル</b><br>
      　メニューに戻ります。<br>
    </td>
  </tr>
  <tr>
    <td></td>
    <td valign="top">
      <b>設定の初期化 画面</b><br><br>
      キーマップ、登録した画像、サウンド設定などの全ての設定をリセットします。<br>
      <br>
      <b>初期化する</b><br>
      　リセットしてM5StackCore2を再起動します。<br>
      <br>
      <b>キャンセル</b><br>
      　メニューに戻ります。<br>
    </td>
  </tr>
  <tr>
    <td></td>
    <td valign="top">
      <b>ファームウェア 画面</b><br><br>
      現在動作しているファームウェアのバージョン確認と、ファームウェアのアップデートができます。<br>
      <b>キャンセル</b><br>
      　メニューに戻ります。<br>
      <br>
      ※ この機能はAZ-Macro用の物でM5StackCore2ではUSB経由でファームウェアのアップデートをして下さい。
    </td>
  </tr>
</table>

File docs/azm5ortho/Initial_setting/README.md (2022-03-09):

# 初期設定

<br><br>

## 対応しているキーボード
- えむごっち
- AZ-M5ortho

<br><br>

## ドライバのインストール
<table>
  <tr>
    <td></td>
    <td>
      まずはM5StackCore2のドライバをインストールします。<br>
      (既にM5Stackの開発環境が整っている場合は必要ありません。)<br><br>
      <a href="https://shop.m5stack.com/pages/download" target="_blank"> https://shop.m5stack.com/pages/download</a> にアクセスしお使いのOSに合った 「 <b>CP2104 Driver</b> 」をダウンロードします。
    </td>
  </tr>
  <tr>
    <td></td>
    <td>
      利用しているPCに合ったファイルを実行してドライバをインストールして下さい。<br>
      （私の場合はWindows10、64bitCPU のため「 CP210xVCPInstaller_x64_v6.7.0.0.exe 」でした。）
    </td>
  </tr>
</table>

<br><br>

## ファームウェアの書込み
<table>
  <tr>
    <td></td>
    <td valign="top">
      ドライバのインストールが終わったらM5StackCore2をPCにUSBでつなぎます。<br><br>
      その後 <b>Chrome</b> で <a href="https://azkey.jp/azm5ortho/" target="_blank">https://azkey.jp/azm5ortho/</a> を開き、ファームウェア欄の「 <b>Version　0.2.8　書込み</b> 」をクリックします。<br>
      <br>
      ※ Versionは最新の物のボタンが表示されています。<br>
      ※ 必ずChromeで開いて下さい。
    </td>
  </tr>
  <tr>
    <td></td>
    <td valign="top">
      ドライバが正しくインストールされていればシリアルポートのデバイスが出てくるので、選択して「接続」をクリックします。
    </td>
  </tr>
  <tr>
    <td></td>
    <td valign="top">
      接続されるとボタンの下に書込みステータスが表示され、書き込みが始まります。<br><br>
      ※ 他のアプリケーションでシリアルポートを使用している最中は書込みできないので、シリアルポートを使用しているアプリケーションは閉じて下さい。<br>
      ※ 書込みをする時M5Stackの電源は入れた状態にして下さい。<br>
      ※ 書込みが失敗する場合はChromeを再起動したり、M5StackCore2のUSBを抜き差ししてもう一度お試しください。<br>
    </td>
  </tr>
  <tr>
    <td></td>
    <td valign="top">
     <b> finish</b> と表示されたら書込み完了です。<br>
     自動的にM5StackCore2が再起動するので、起動するまでお待ちください。<br><br>
     ※ 一番最初に書き込む場合は再起動後ROM内の初期化が行われるため1分半ほど起動に時間がかかります。画面が暗いままですがそのままお待ちください。
    </td>
  </tr>
</table>

<br><br>

## 接続しているキーボードの選択
<table>
  <tr>
    <td></td>
    <td valign="top">
      初回起動時のみ現在接続しているキーボードの選択画面が表示されます。<br>
      接続しているキーボードを選択し「 決定 」をタップしてください。
    </td>
  </tr>
  <tr>
    <td><br></td>
    <td valign="top">
      M5StackCore2が再起動され待ち受け画像が表示されたら初期設定完了です。<br><br>
      この状態でPCからBluetooth機器を検索するとキーボードが出てきます。
    </td>
  </tr>
</table>

<br>

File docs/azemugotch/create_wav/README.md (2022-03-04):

# 登録用のWAVファイル作成方法

<br><br>

<table>
  <tr>
    <td></td>
    <td valign="top">
      フリーの効果音素材を配布している効果音ラボさんなどから、打鍵に使いたい効果音を選んでダウンロードします。<br><br>
       → <a href="https://soundeffect-lab.info/sound/button/" target="_blank">https://soundeffect-lab.info/sound/button/</a><br><br>
       １．効果音名の所を押すと音が再生されるので、聞いてみて設定したい音を選びます。<br><br>
       ２．決まったら<b>ＤＬ</b>のボタンを押すとダウンロードできます。
    </td>
  </tr>
  <tr>
    <td></td>
    <td valign="top">
      オンラインで音ファイルを変換できる<b>オーディオコンバータ</b>さんを開きます。<br><br>
       → <a href="https://online-audio-converter.com/ja/" target="_blank">https://online-audio-converter.com/ja/</a>
    </td>
  </tr>
  <tr>
    <td></td>
    <td valign="top">
      １．先ほどダウンロードしたMP3ファイルを選びます。<br><br>
      ２．変換したい種類を <b>wav</b> にします。<br><br>
      ３．<b>詳細設定</b> を押します。<br><br>
      ４．変化後のサンプルレートを設定します。<br>
      　サンプルレートが低いほど容量も小さく長い時間再生できますが、小さすぎると音が割れます。<br>
      　ここでは一旦 <b>16000Khz</b> を選択します。<br><br>
      ５．チャンネル数はモノラルにしたいので、<b>1</b>を選択します。<br><br>
      ６．<b>変換</b> を押すとwavファイルに変換されます。<br><br>
    </td>
  </tr>
  <tr>
    <td></td>
    <td valign="top">
      変換が終わると「変換を完了しました」と表示されます。
      <b>ダウンロード</b> を押すと変換したwavファイルをダウンロードできます。
    </td>
  </tr>
</table>

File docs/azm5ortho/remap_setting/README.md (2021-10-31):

# REMAP 設定方法

<br><br>

<table>
  <tr>
    <td></td>
    <td valign="top">
      １．AZ-M5ortho をBluetoothでペアリングした状態でChromeからREMAPのサイトを開きます。<br><br>
      REMAP → <a href="https://remap-keys.app/" target="_blank">https://remap-keys.app/</a><br><br>
      ２．「START REMAP FOR YOUR KEYBOARD」をクリックします。
    </td>
  </tr>
  <tr>
    <td></td>
    <td valign="top">
      「+KEYBOARD」をクリックします。
    </td>
  </tr>
  <tr>
    <td></td>
    <td valign="top">
      接続するデバイスを選択するウィンドウが出るので「02E5:11A1」を選択して「接続」をクリックします。
    </td>
  </tr>
  <tr>
    <td></td>
    <td valign="top">
      キー設定の画面に切り替わります。
    </td>
  </tr>
  <tr>
    <td></td>
    <td valign="top">
      下に並んでるキーをドラックしてキー配列上へ持ってくるとキーの設定を変更する事ができます。
    </td>
  </tr>
  <tr>
    <td></td>
    <td valign="top">
      設定が完了したら右上の「Flash」をクリックすると設定がキーボードに反映されます。
    </td>
  </tr>
</table>

<br><br>

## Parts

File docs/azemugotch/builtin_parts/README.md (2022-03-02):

# えむごっち 入っている物
<br>

## ベースキット
<table>
  <tr>
    <th>写真</th>
    <th>パーツ名</th>
    <th>個数</th>
  </tr>
  <tr>
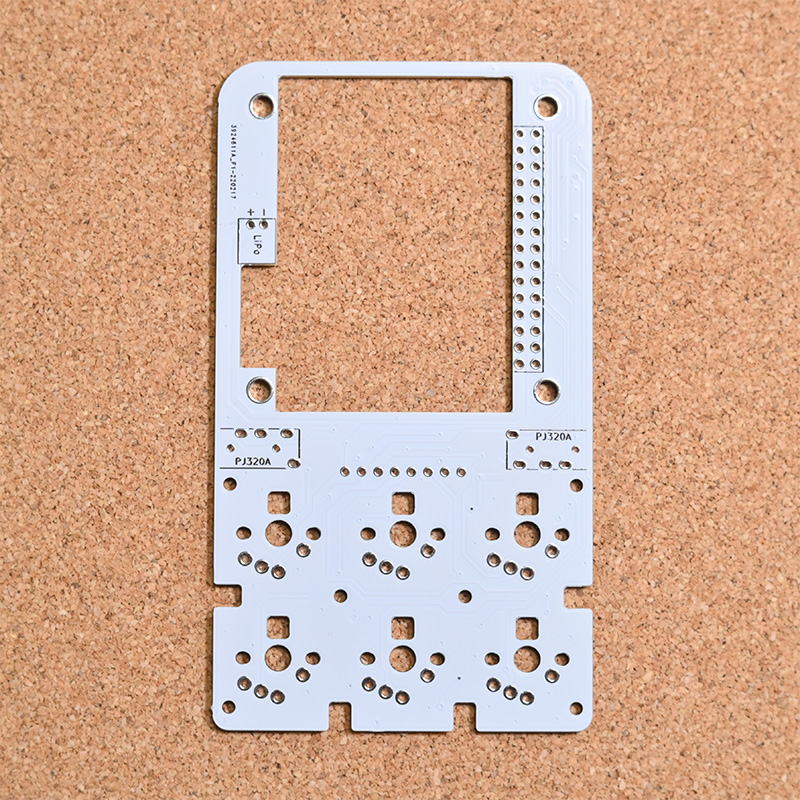
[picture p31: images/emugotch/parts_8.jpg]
    <td></td>
    <td>PCB プレート</td>
    <td valign="center">1</td>
  </tr>
  <tr>
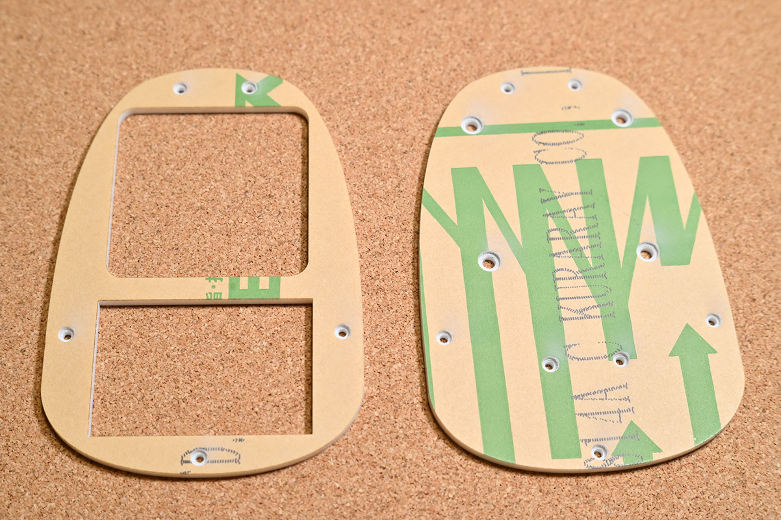
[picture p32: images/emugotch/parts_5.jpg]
    <td></td>
    <td>トッププレート<br>ボトムプレート<br>(アクリル 白 両面マット 3mm)</td>
    <td valign="center">1</td>
  </tr>
  <tr>
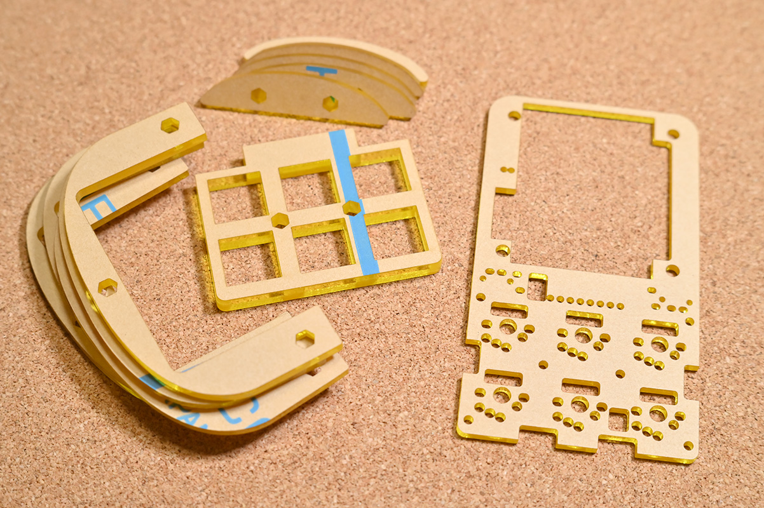
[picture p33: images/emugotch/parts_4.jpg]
    <td></td>
    <td>ミドルプレート上 × 5<br>ミドルプレート下 × 5<br>(アクリル 黄クリア 3mm)<br><br>キートッププレート × 1<br>(アクリル 黄クリア 5mm)<br><br>ミドル裏プレート × 1<br>(アクリル 黄クリア 2mm)</td>
    <td valign="center">1</td>
  </tr>
  <tr>
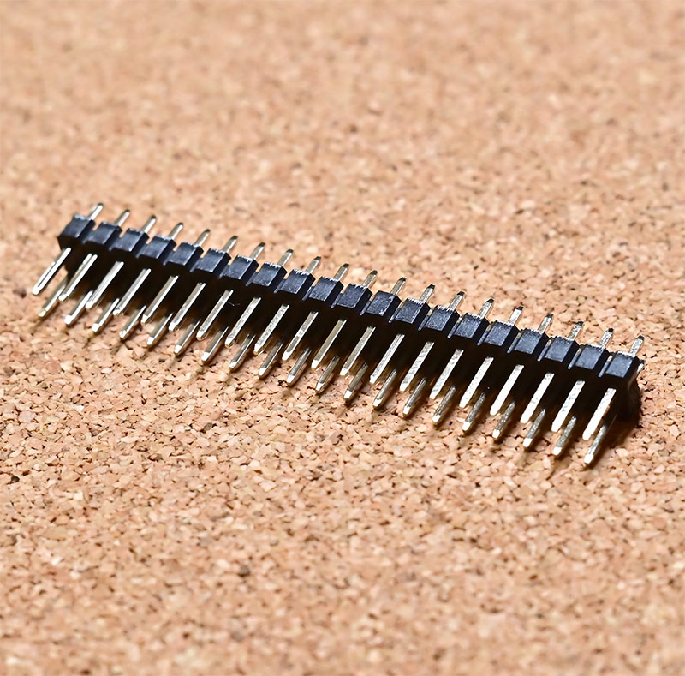
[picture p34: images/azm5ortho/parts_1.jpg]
    <td></td>
    <td>ピンヘッダ (2x20)</td>
    <td valign="center">1</td>
  </tr>
  <tr>
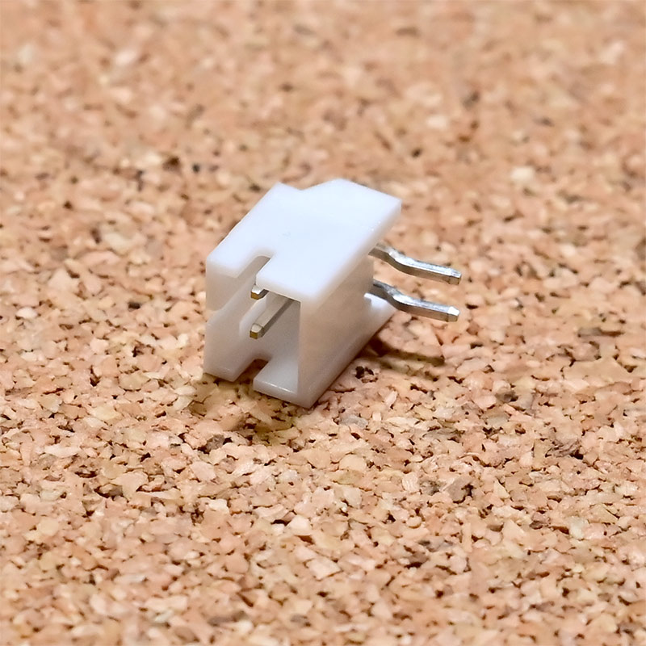
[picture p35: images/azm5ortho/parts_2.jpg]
    <td></td>
    <td>PHコネクタ</td>
    <td valign="center">1</td>
  </tr>
  <tr>
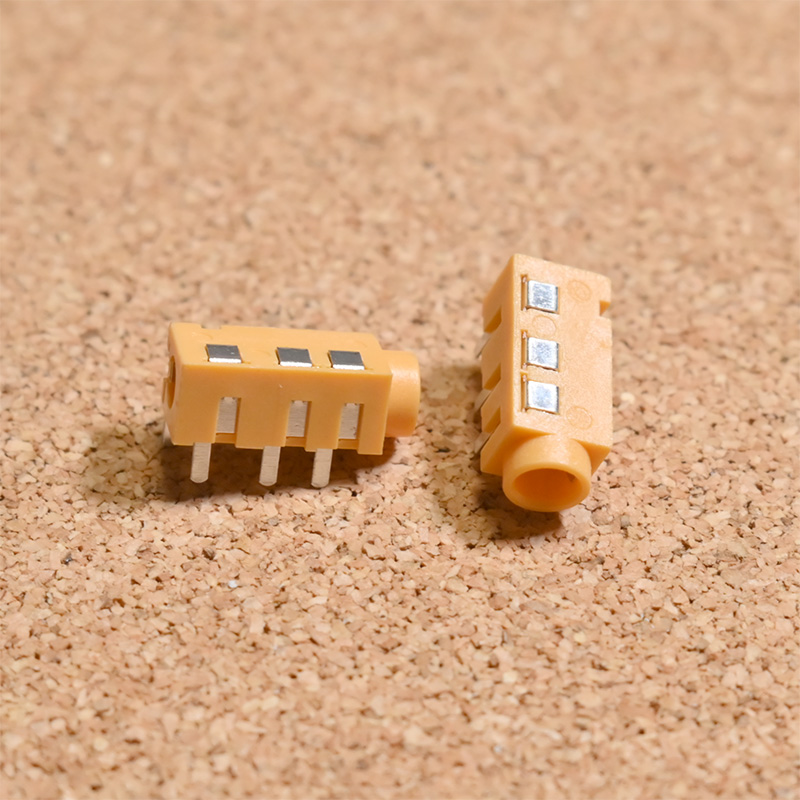
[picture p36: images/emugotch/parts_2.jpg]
    <td></td>
    <td>TRRSジャック (PJ320A)</td>
    <td valign="center">2</td>
  </tr>
  <tr>
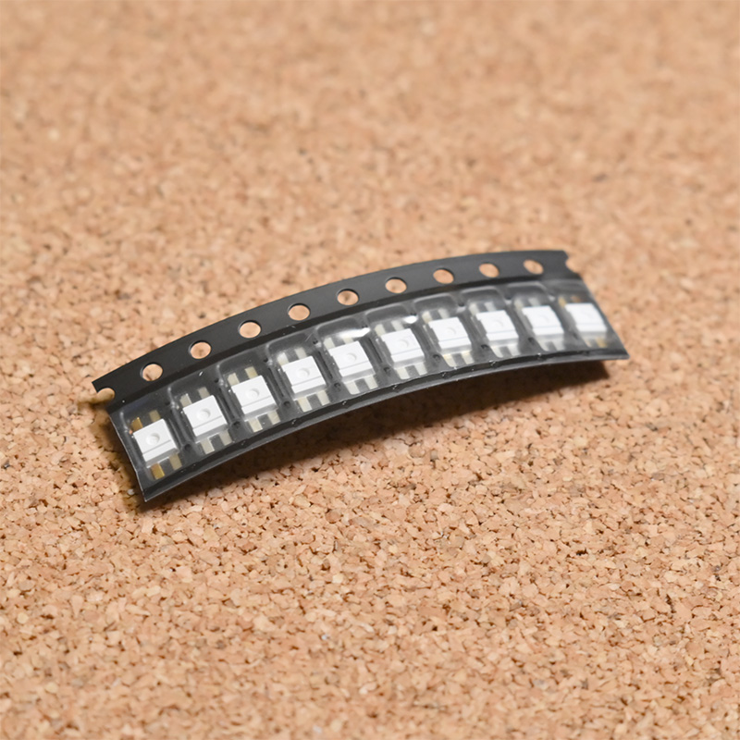
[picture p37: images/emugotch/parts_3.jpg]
    <td></td>
    <td>カラーLED (SK6812MINI-E)</td>
    <td valign="center">10</td>
  </tr>
  <tr>
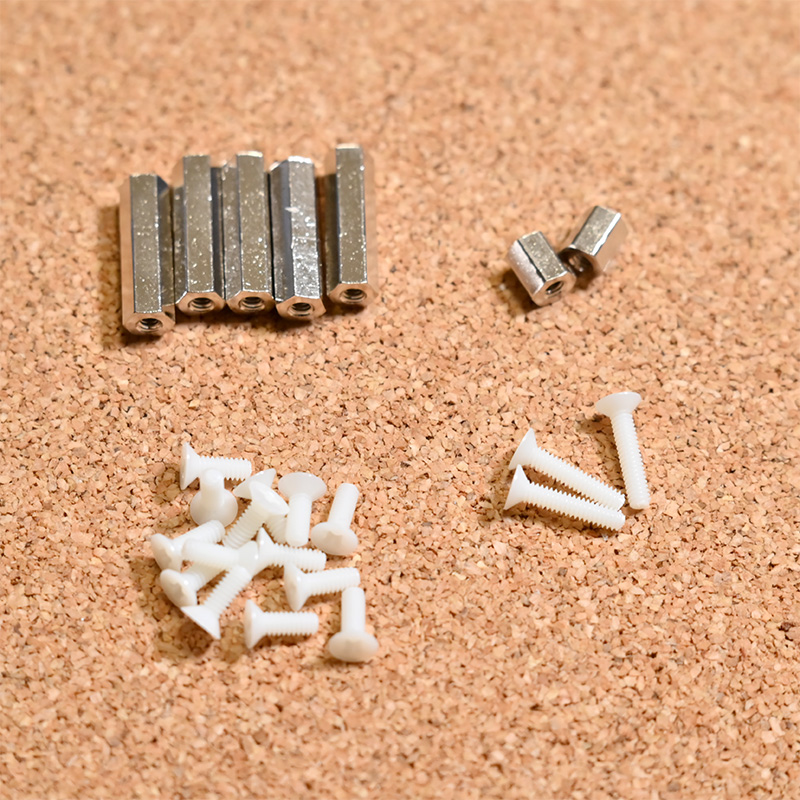
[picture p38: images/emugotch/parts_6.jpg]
    <td></td>
    <td>M2 六角スペーサー 14.5mm × 5<br>M2 六角スペーサー 5mm × 2<br>M2 樹脂ネジ 6mm × 12<br>M2 樹脂ネジ 10mm × 3</td>
    <td valign="center">1</td>
  </tr>
  <tr>
    <td></td>
    <td>M3 スリムヘッド 16mm × 2<br>M3 スリムヘッド 20mm × 2</td>
    <td valign="center">1</td>
  </tr>
  <tr>
    <td></td>
    <td>六角レンチ (2mm)</td>
    <td valign="center">1</td>
  </tr>
  <tr>
    <td></td>
    <td>ゴム足 × 4</td>
    <td valign="center">1</td>
  </tr>
</table>

<br><br>

## 各カラープレート
<table>
  <tr>
    <th>写真</th>
    <th>パーツ名</th>
    <th>個数</th>
  </tr>
  <tr>
    <td></td>
    <td>トッププレート<br>ボトムプレート<br>(アクリル 片面マット 3mm)</td>
    <td valign="center">1</td>
  </tr>
</table>

<br>
<br>

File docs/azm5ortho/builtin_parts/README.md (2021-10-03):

# AZ-M5ortho 入っている物
<br>

## PCB プレート
<table>
  <tr>
    <th>写真</th>
    <th>パーツ名</th>
    <th>個数</th>
  </tr>
  <tr>
    <td></td>
    <td>PCB プレート</td>
    <td valign="center">1</td>
  </tr>
  <tr>
    <td></td>
    <td>ピンヘッダ (2x20)</td>
    <td valign="center">1</td>
  </tr>
  <tr>
    <td></td>
    <td>PHコネクタ</td>
    <td valign="center">1</td>
  </tr>
  <tr>
    <td></td>
    <td>CherryMXソケット</td>
    <td valign="center">55</td>
  </tr>
  <tr>
    <td></td>
    <td>六角レンチ (2mm)</td>
    <td valign="center">1</td>
  </tr>
</table>

<br><br>

## プレートセット
<table>
  <tr>
    <th>写真</th>
    <th>パーツ名</th>
    <th>個数</th>
  </tr>
  <tr>
    <td></td>
    <td>トッププレート (5mm厚)</td>
    <td valign="center">1</td>
  </tr>
  <tr>
    <td></td>
    <td>ミドルプレート (2mm厚)</td>
    <td valign="center">1</td>
  </tr>
  <tr>
    <td></td>
    <td>ボトムプレート (2mm厚)</td>
    <td valign="center">1</td>
  </tr>
  <tr>
    <td></td>
    <td>プレート固定用のネジ (M2 12mm x 12本)<br>プレート固定用の六角ナット (M2)</td>
    <td valign="center">12</td>
  </tr>
  <tr>
    <td></td>
    <td>M5StackCore2 固定用のネジ (M3 15mm x 2本、 M3 20mm x 2本)</td>
    <td valign="center">4</td>
  </tr>
  <tr>
    <td></td>
    <td>ゴム足</td>
    <td valign="center">8</td>
  </tr>
</table>

<br>
<br>

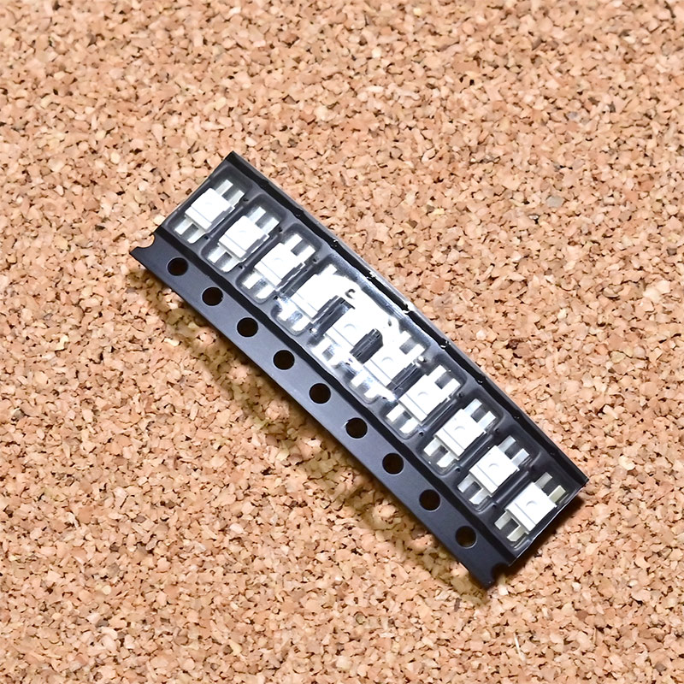
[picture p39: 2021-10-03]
images/azm5ortho/parts_8.jpg

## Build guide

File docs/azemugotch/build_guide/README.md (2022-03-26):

# えむごっち 組み立て手順

<br><br>

## 使う道具
<table>
  <tr>
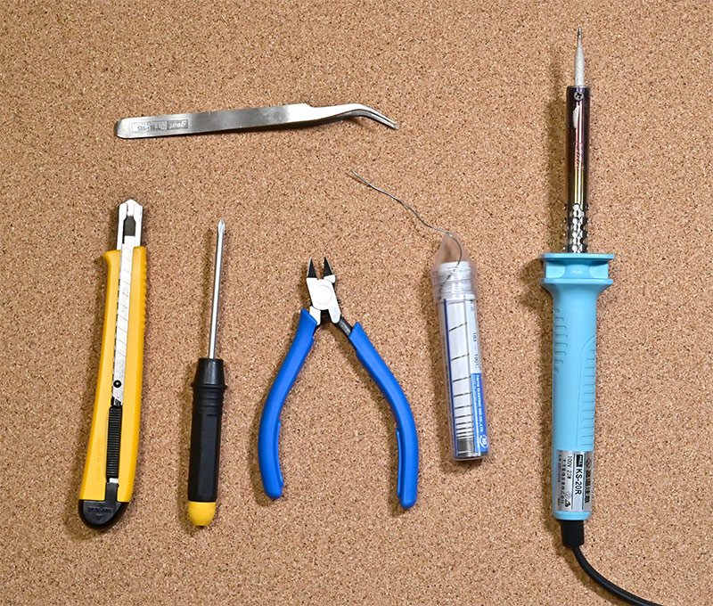
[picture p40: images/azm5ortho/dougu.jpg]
    <td></td>
    <td>
      カッター<br>
      プラスドライバー（小）<br>
      ピンセット<br>
      ニッパー<br>
      はんだ<br>
      はんだごて
    </td>
  </tr>
</table>

<br><br>

## カラーLEDのはんだ付け
<table>
  <tr>
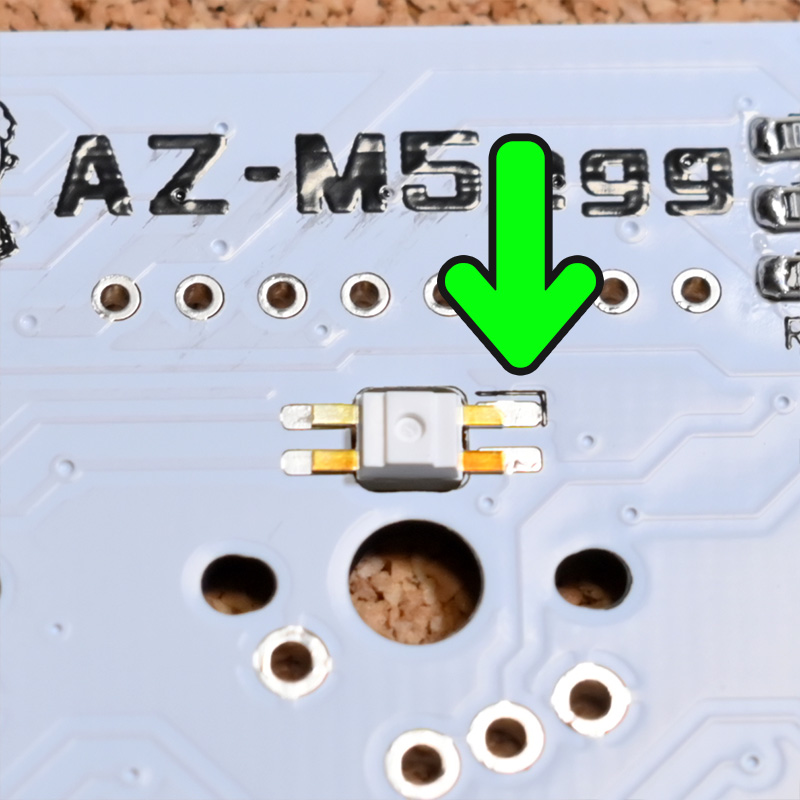
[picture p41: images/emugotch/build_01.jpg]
    <td></td>
    <td valign="top">
      <b>向き合わせ</b><br>
      PCBについている黒線マークと、LEDの足の角が欠けている方向を一緒にして下さい。<br>
      向きを間違えると他のLEDも含め動作しなくなるので注意して下さい。
    </td>
  </tr>
  <tr>
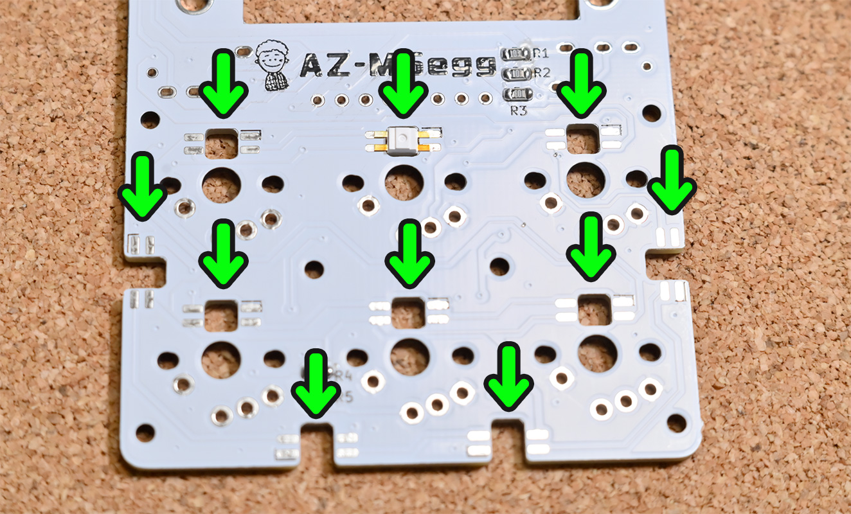
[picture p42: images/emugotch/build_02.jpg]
    <td></td>
    <td valign="top">
      全部で10ヶ所あるのでそれぞれ向きに注意してはんだ付けして下さい。
    </td>
  </tr>
</table>

<br><br>

## TRRSジャックのはんだ付け
<table>
  <tr>
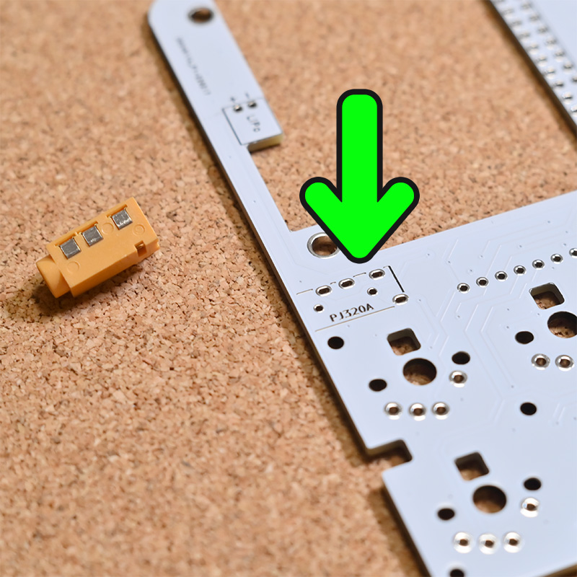
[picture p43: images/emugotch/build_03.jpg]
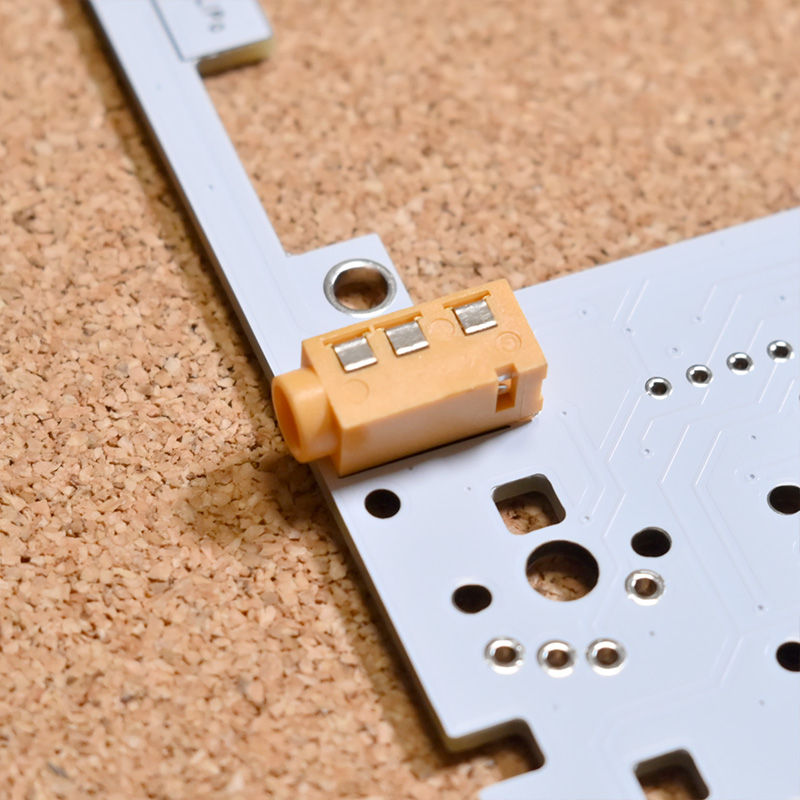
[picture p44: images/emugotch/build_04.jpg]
    <td><br></td>
    <td valign="top">
      PJ320Aと書いてある表から差し込んで裏側をはんだ付けして下さい。
    </td>
  </tr>
</table>

<br><br>

## PHコネクタのはんだ付け
<table>
  <tr>
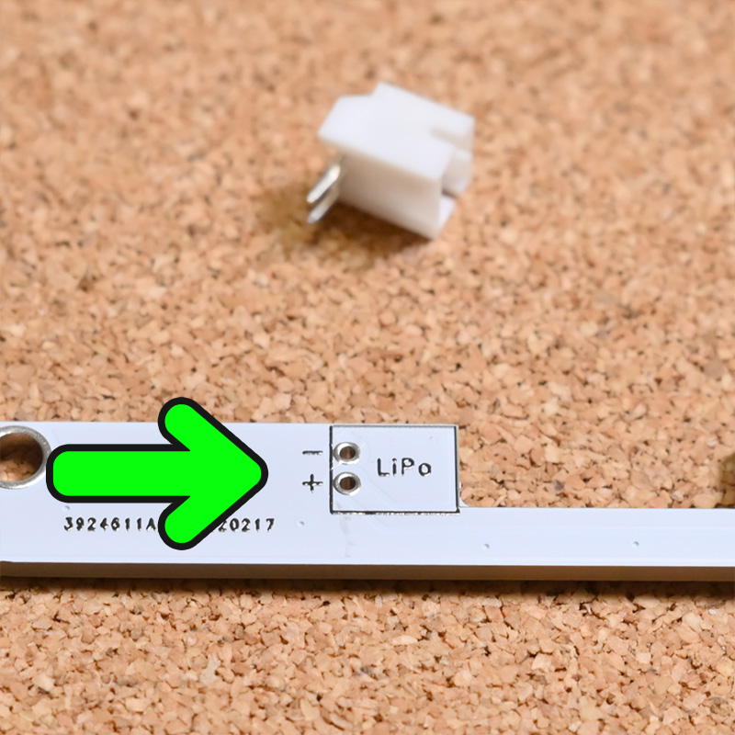
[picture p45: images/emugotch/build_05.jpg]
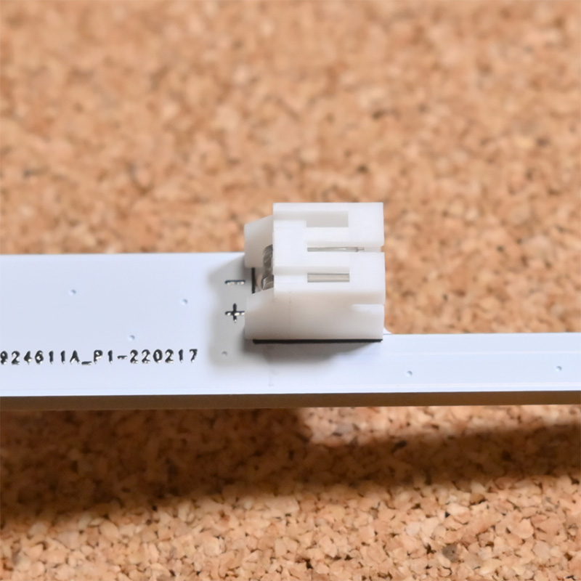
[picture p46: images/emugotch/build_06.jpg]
    <td><br></td>
    <td valign="top">
      PHコネクタも表側から差し込み裏側をはんだ付けします。<br>
      ※ 誤って表裏逆にさすと＋、－が逆になってしまうので気を付けて下さい。
    </td>
  </tr>
</table>

<br><br>

## ピンヘッダのはんだ付け
<table>
  <tr>
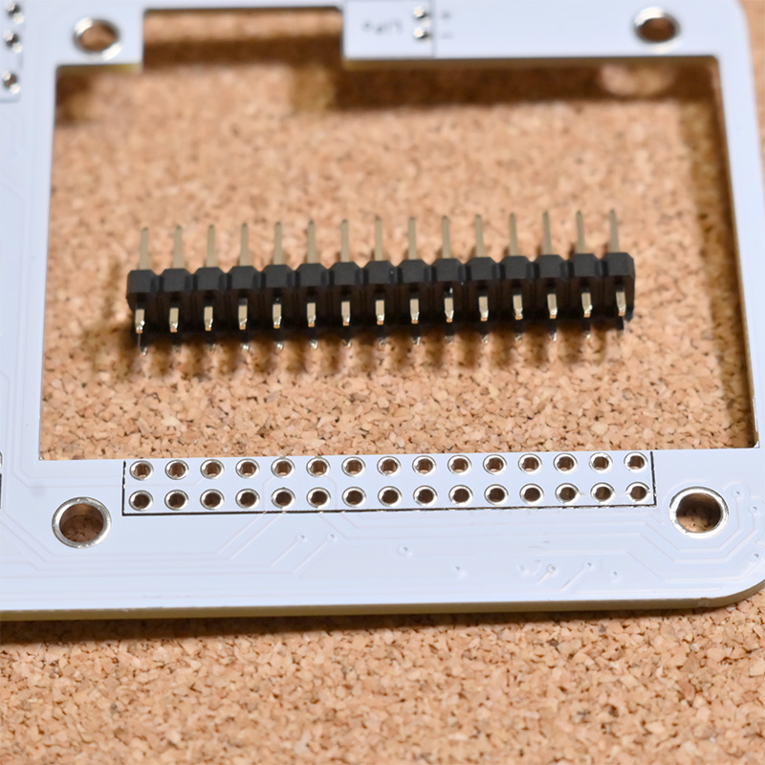
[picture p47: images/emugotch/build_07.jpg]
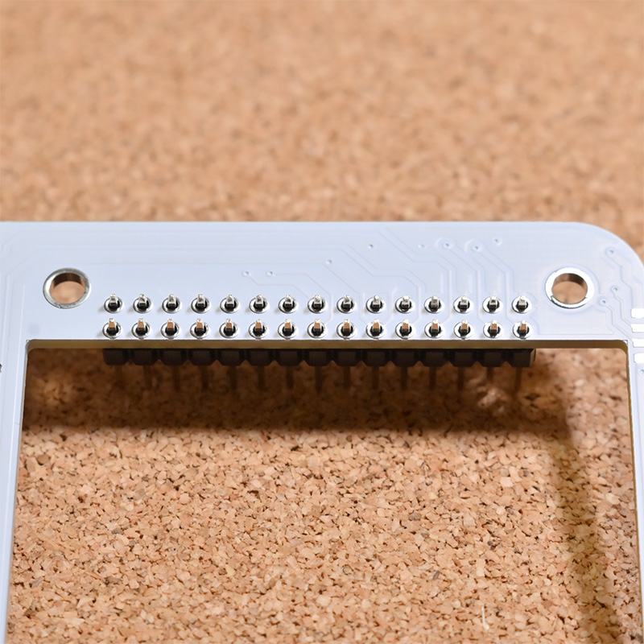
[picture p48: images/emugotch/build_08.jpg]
    <td><br></td>
    <td valign="top">
      ニッパーなどでピンヘッダを幅15ピンでカットし、PCBの表側から差し込み、裏側裏側をはんだ付けします。<br>
      ※ この位置が重要でピンヘッダが斜めに刺さっていたりズレたりするとM5StackCore2の位置がズレます。<br>
      ※ 心配な方はM5StackCore2にピンヘッダを差し込んだ状態ではんだ付けするとズレずにはんだ付けできます。
    </td>
  </tr>
</table>

<br><br>

## はんだ付け例
<table>
  <tr>
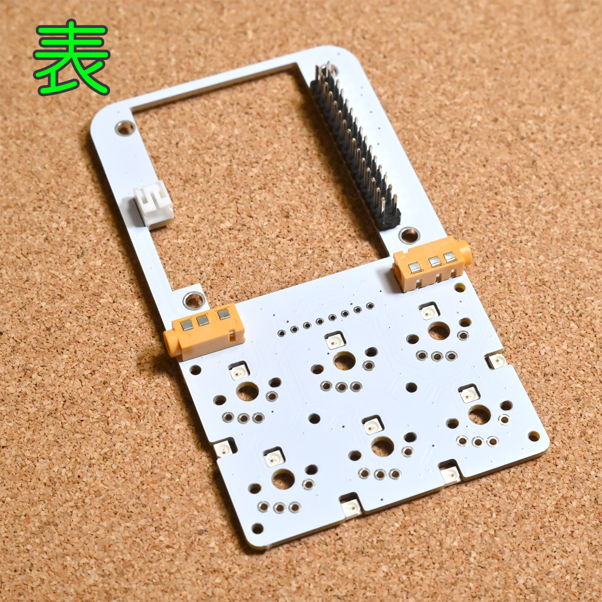
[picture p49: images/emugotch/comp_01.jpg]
    <td></td>
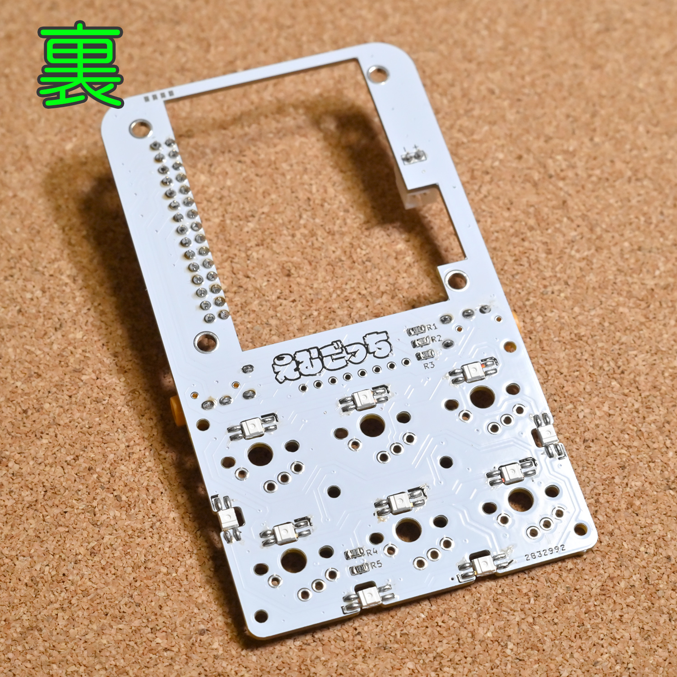
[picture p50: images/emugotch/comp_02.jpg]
    <td></td>
  </tr>
</table>

<br><br>

comp_01.jpg

## スイッチのはんだ付け
<table>
  <tr>
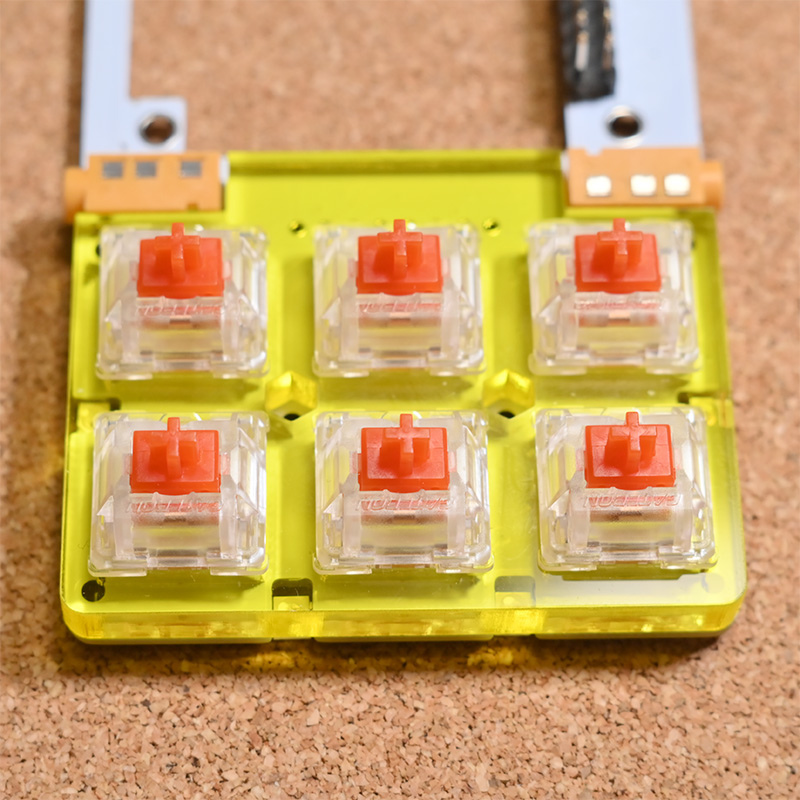
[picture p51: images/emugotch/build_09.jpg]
    <td></td>
    <td valign="top">
      PCBの表面に キートッププレート が挟まるようにスイッチを差し込んで下さい。<br><br>
      ※ スイッチがハマりやすい面とハマりにくい面があります。硬くてスイッチが入らない場合は反対面に差し込んで下さい。
    </td>
  </tr>
  <tr>
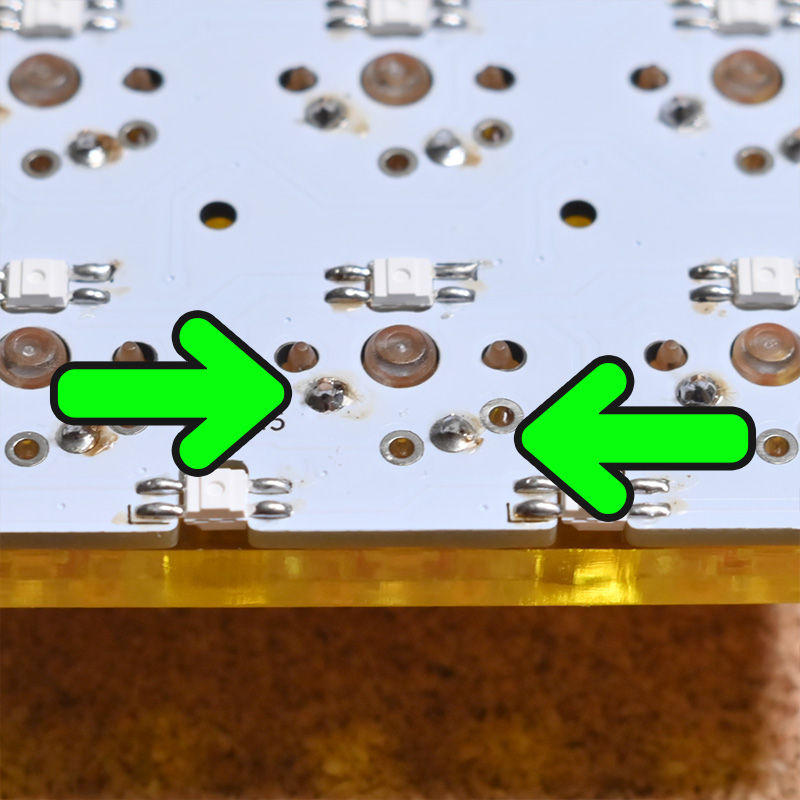
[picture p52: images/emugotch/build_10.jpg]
    <td></td>
    <td valign="top">
      裏側からスイッチの足をはんだ付けして下さい。
    </td>
  </tr>
</table>

<br><br>

## プレートの固定
<table>
  <tr>
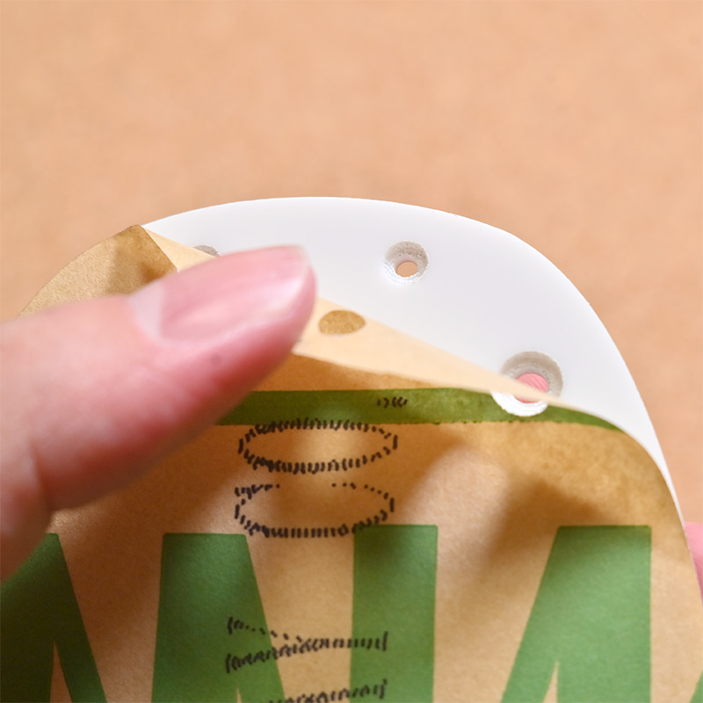
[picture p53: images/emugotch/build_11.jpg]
    <td></td>
    <td valign="top">
      まず各プレートの保護シートをはがします。<br>
      ※ ミドルプレートが割れやすいのでカッターなどを使用し少しずつはがして下さい。
    </td>
  </tr>
  <tr>
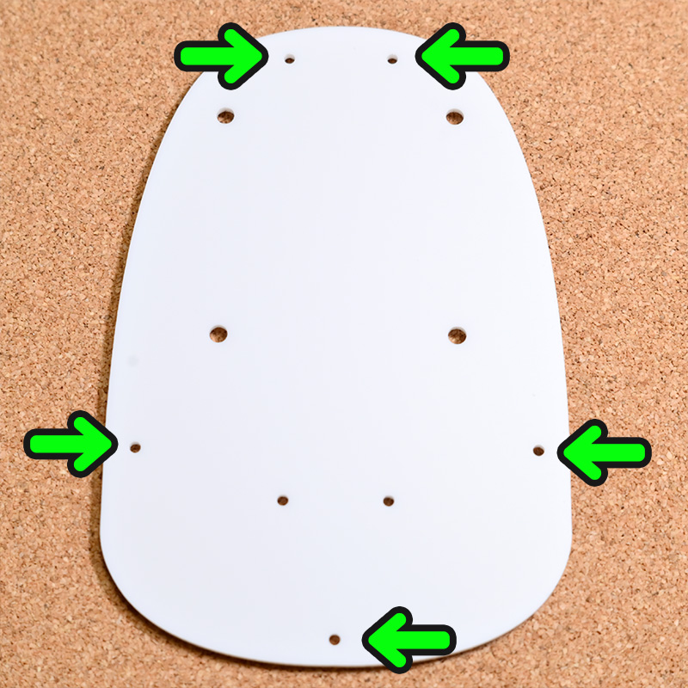
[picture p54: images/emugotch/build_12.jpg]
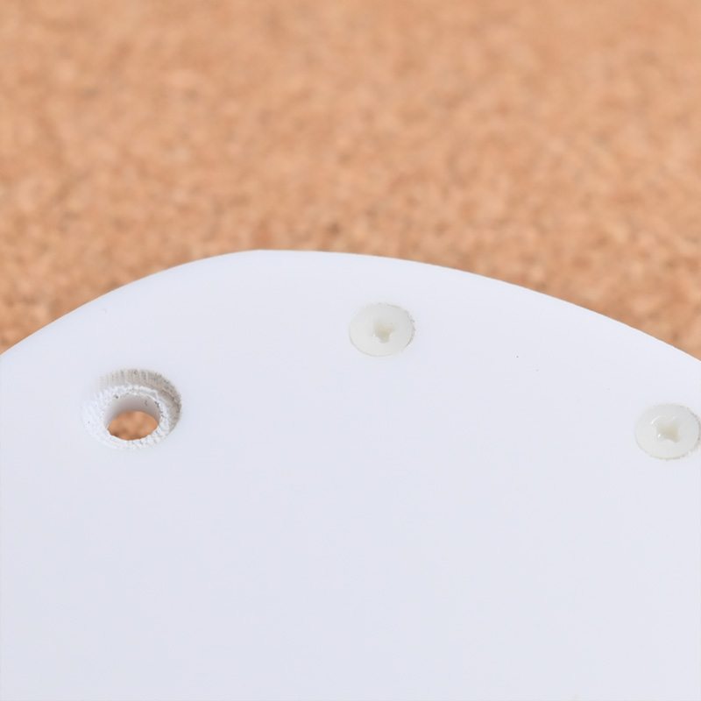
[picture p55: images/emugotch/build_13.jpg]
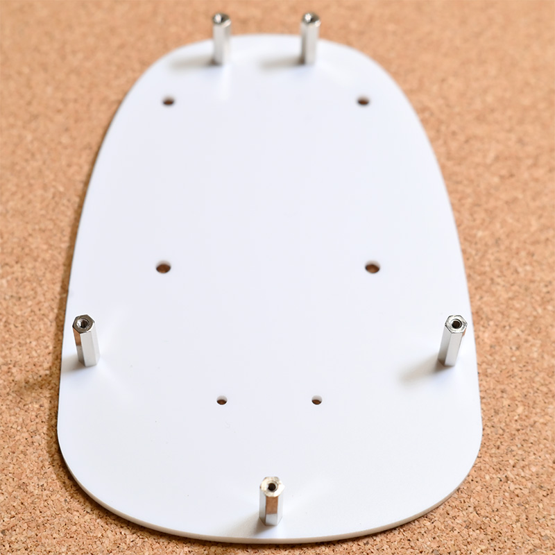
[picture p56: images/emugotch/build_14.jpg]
    <td><br><br></td>
    <td valign="top">
      ボトムプレートの矢印部分に<b>14.5mmの六角スペーサー</b>を<b>M2 6mm 樹脂ネジ</b>で固定して下さい。<br>全部で5か所あります。<br>プレートに凹みがある方にネジを差し込んで下さい。<br><br>
      ※ ネジ山が削れやすいので力を入れすぎないよう気をつけてください。
    </td>
  </tr>
  <tr>
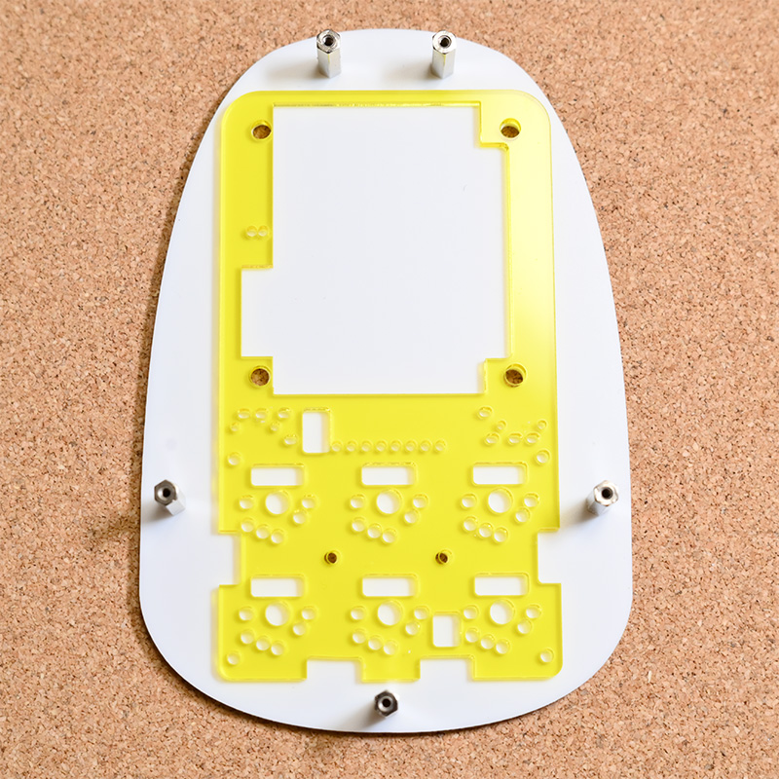
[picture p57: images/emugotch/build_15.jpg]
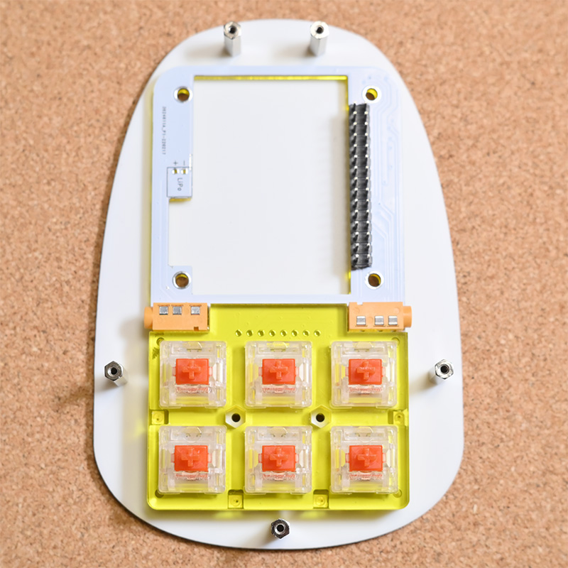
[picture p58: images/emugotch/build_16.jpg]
    <td><br></td>
    <td valign="top">
      ボトムプレートの上にミドル裏プレート、PCBプレートを乗せて下さい。
    </td>
  </tr>
  <tr>
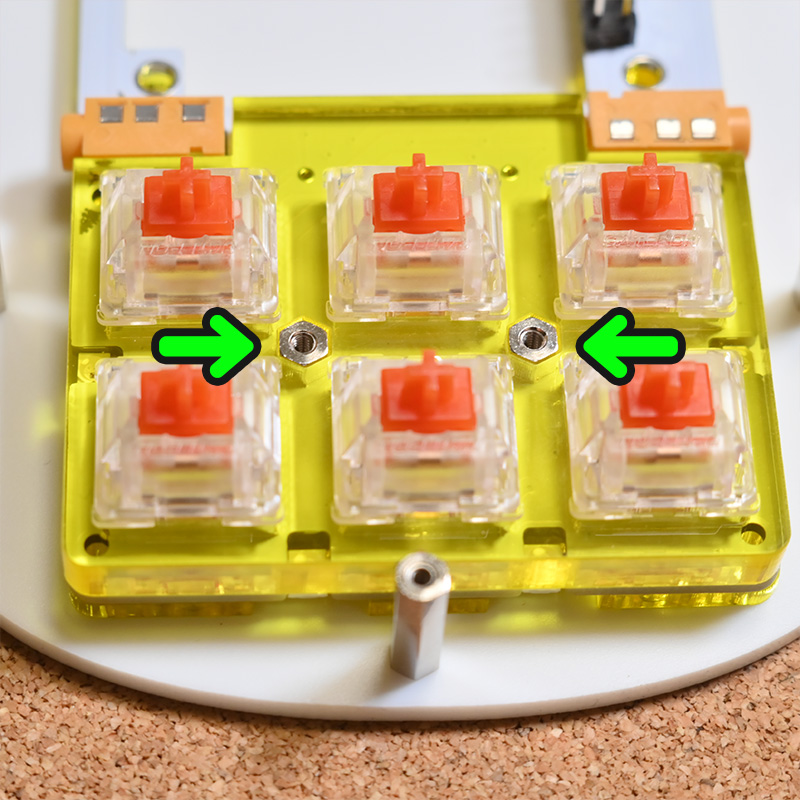
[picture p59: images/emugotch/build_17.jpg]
    <td></td>
    <td valign="top">
      スイッチの間に六角形の穴があるので<b>六角 5mm スペーサー</b>を入れ、裏から<b>M2 10mm 樹脂ネジ</b>でとめて下さい。<br><br>
      ※ ネジ山が削れやすいので力を入れすぎないよう気をつけてください。
    </td>
  </tr>
  <tr>
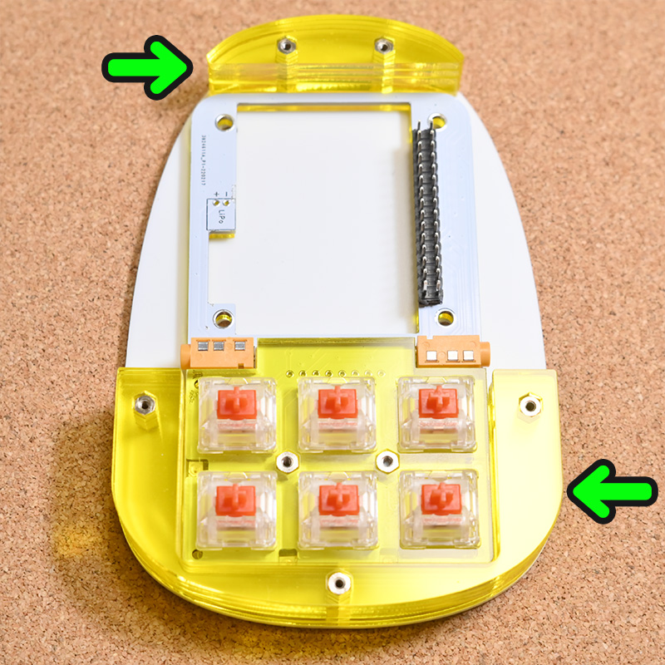
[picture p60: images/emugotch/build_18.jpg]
    <td></td>
    <td valign="top">
      上部に<b>ミドルプレート上</b>を5つ、下部に<b>ミドルプレート下</b>を5つはめ込んで下さい。<br>六角スペーサーの角度があるので合わない場合はスペーサを少しゆるめてからはめ込んで下さい。
    </td>
  </tr>
  <tr>
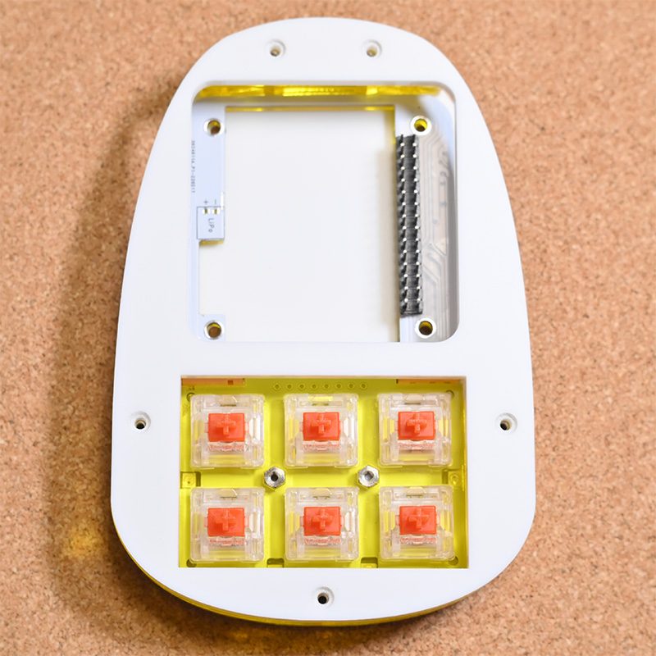
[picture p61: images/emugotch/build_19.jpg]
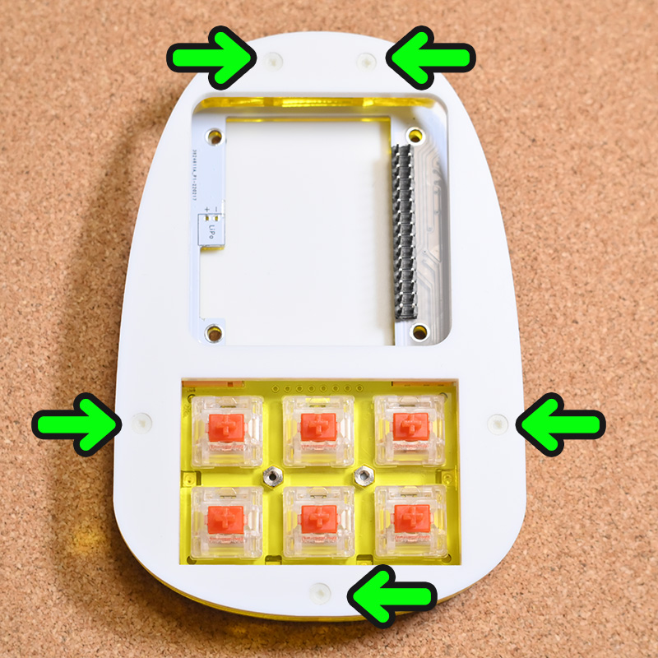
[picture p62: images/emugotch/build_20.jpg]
    <td><br></td>
    <td valign="top">
      トッププレートを乗せて矢印の部分を<b>M2 6mm 樹脂ネジ</b>でとめて下さい。<br><br>
      ※ ネジ山が削れやすいので力を入れすぎないよう気をつけてください。
    </td>
  </tr>
  <tr>
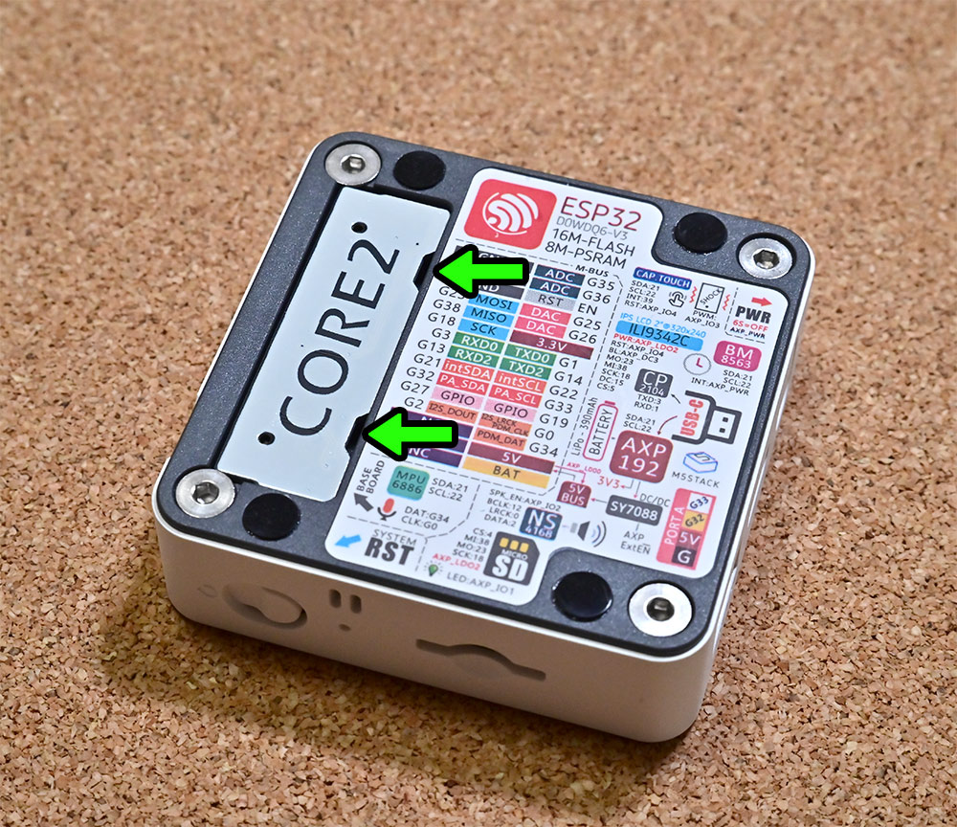
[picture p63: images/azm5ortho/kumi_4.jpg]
    <td></td>
    <td valign="top">
      M5StackCore2 の背面のコネクタ部分のフタを外します。<br>
      2か所穴が開いているのでそこへピンセット等を差し込みテコの原理で外します。
    </td>
  </tr>
  <tr>
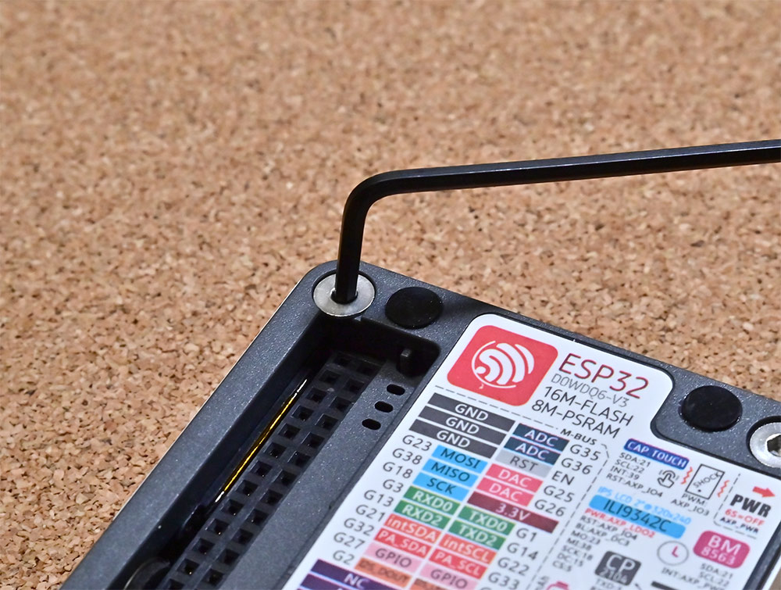
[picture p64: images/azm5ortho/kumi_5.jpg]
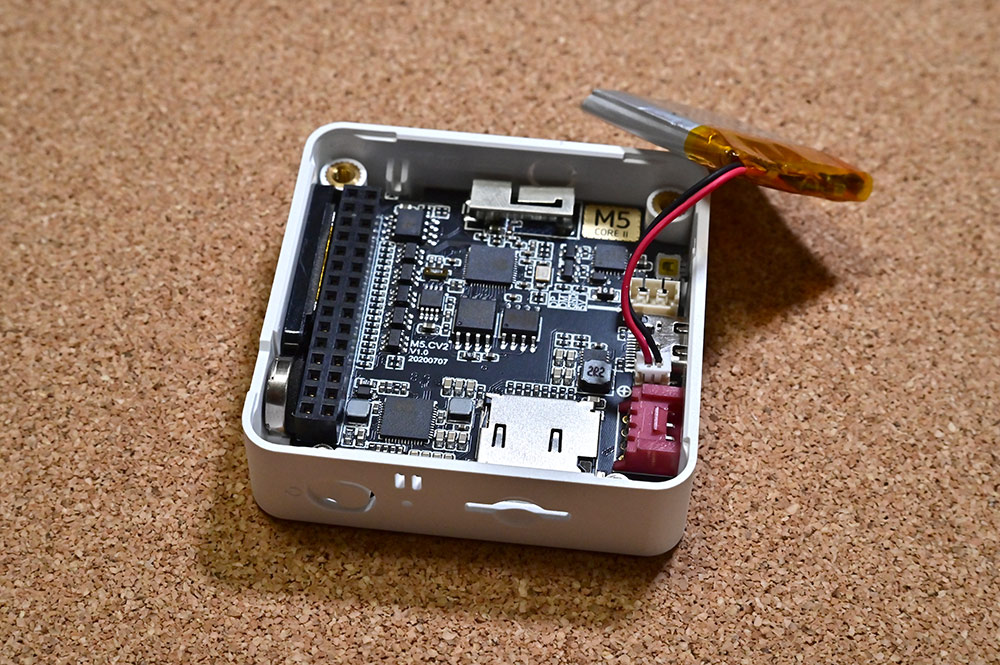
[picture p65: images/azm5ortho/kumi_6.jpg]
    <td><br></td>
    <td valign="top">
      六角レンチで裏面4ヶ所のネジも外します。<br>
      外すとフタにバッテリーが両面テープで固定されているのでフタからバッテリーをはがして下さい。
    </td>
  </tr>
  <tr>
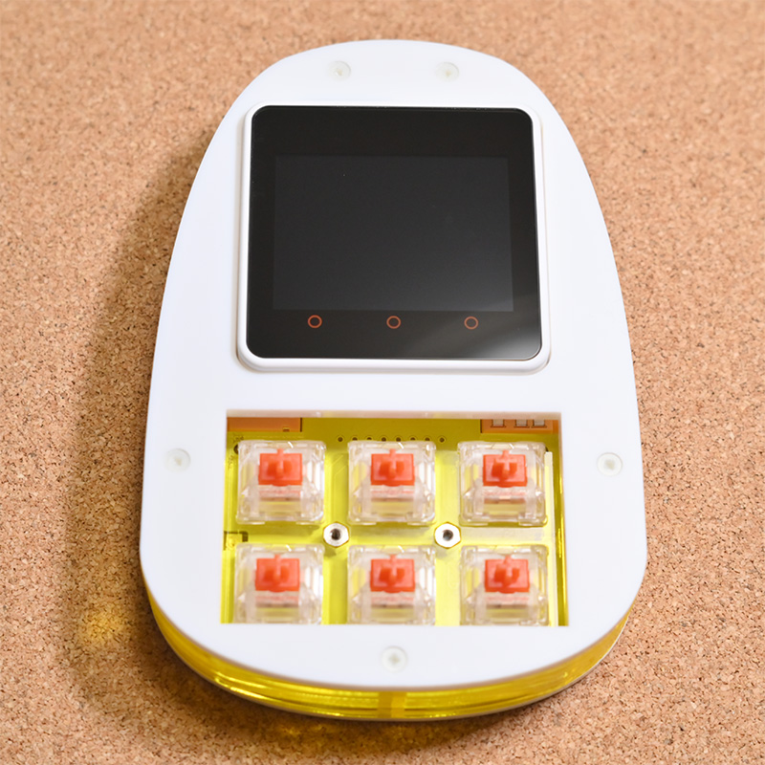
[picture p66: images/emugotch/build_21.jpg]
    <td></td>
    <td valign="top">
      えむごっちの表側からPCBへ差し込んで下さい。<br>うまく位置が合わない場合はPCBを固定しているネジを少しゆるめて位置を合わせて下さい。
    </td>
  </tr>
  <tr>
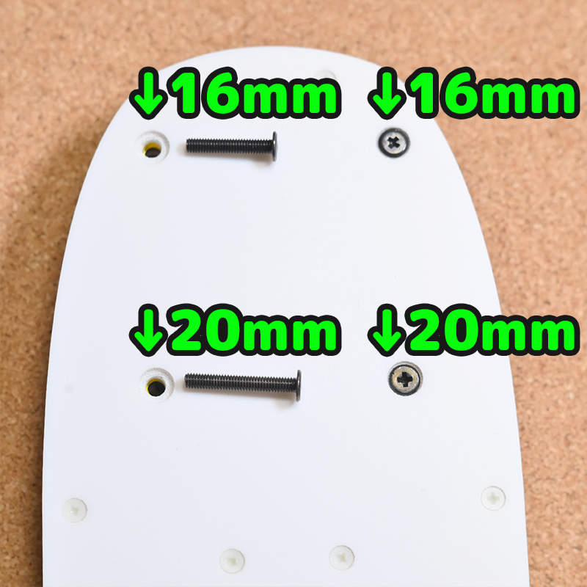
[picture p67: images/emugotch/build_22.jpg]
    <td></td>
    <td valign="top">
      裏側から<b>M3 スリムヘッドネジ</b>でM5StackCore2を固定します。<br>上２箇所が短い16mm、下２箇所が長い20mmのえむごっち付属の黒いネジで固定して下さい。
    </td>
  </tr>
  <tr>
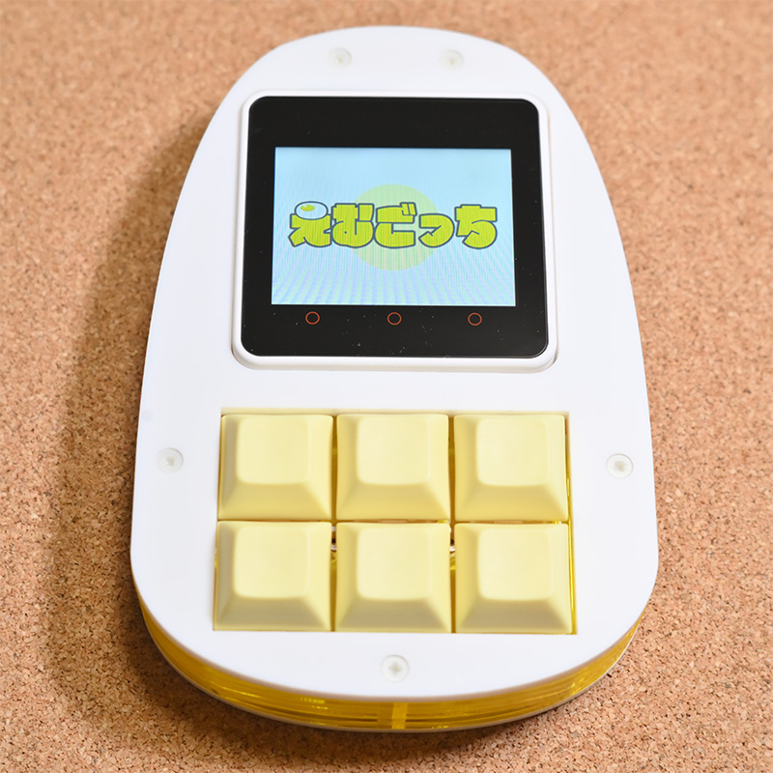
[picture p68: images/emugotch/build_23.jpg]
    <td></td>
    <td valign="top">
      キーキャップをはめ込んで完成です。<br><br>
      ※ お好みで裏面にゴム足を張り付けて下さい。
    </td>
  </tr>
</table>

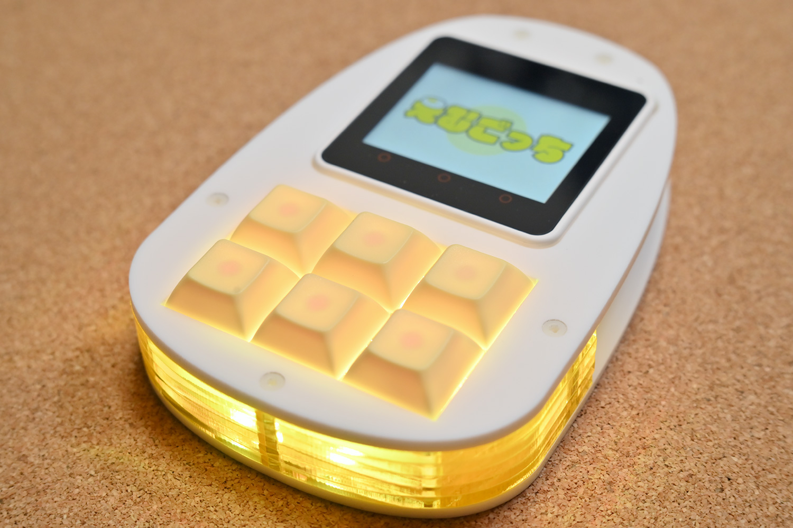
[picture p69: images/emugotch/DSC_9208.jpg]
<br>

ファームウェアは「初期設定マニュアル」に従ってM5StackCore2に書き込みを行って下さい。<br>
[初期設定マニュアル](/docs/azm5ortho/Initial_setting/)

<br>
バッテリーは標準の物を紹介しましたが、PH2ピンのコネクタにささるリチウムバッテリに変更する事も可能です。<br>
変更する場合は400mAh以上の容量のバッテリーをご利用するのと、標準のバッテリーは抜いてご利用ください。<br>

<br>

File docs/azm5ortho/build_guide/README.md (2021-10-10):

# AZ-M5ortho 組み立て手順

<br><br>

## 使う道具
<table>
  <tr>
    <td></td>
    <td>
      カッター<br>
      プラスドライバー（中）<br>
      ピンセット<br>
      ニッパー<br>
      はんだ<br>
      はんだごて
    </td>
  </tr>
</table>

<br><br>

## カラーLEDのはんだ付け
<table>
  <tr>
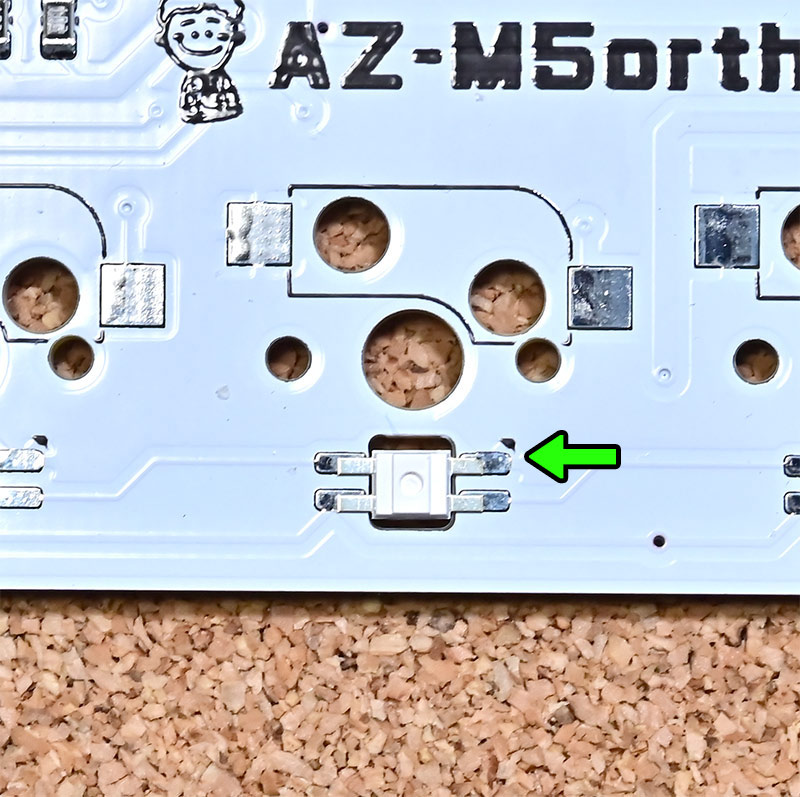
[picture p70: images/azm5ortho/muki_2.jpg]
    <td></td>
    <td valign="top">
      <b>向き合わせ</b><br>
      PCBについている三角マークと、LEDの足の角が欠けている方向を一緒にして下さい。<br>
      向きを間違えると他のLEDも含め動作しなくなるので注意して下さい。<br><br>
      ※ はんだ付けする時ははんだ付け済みのICの足を触ってしまわないよう注意して下さい。ICの足をブリッジしてしまうとキーを認識しなくなる可能性があります。
    </td>
  </tr>
  <tr>
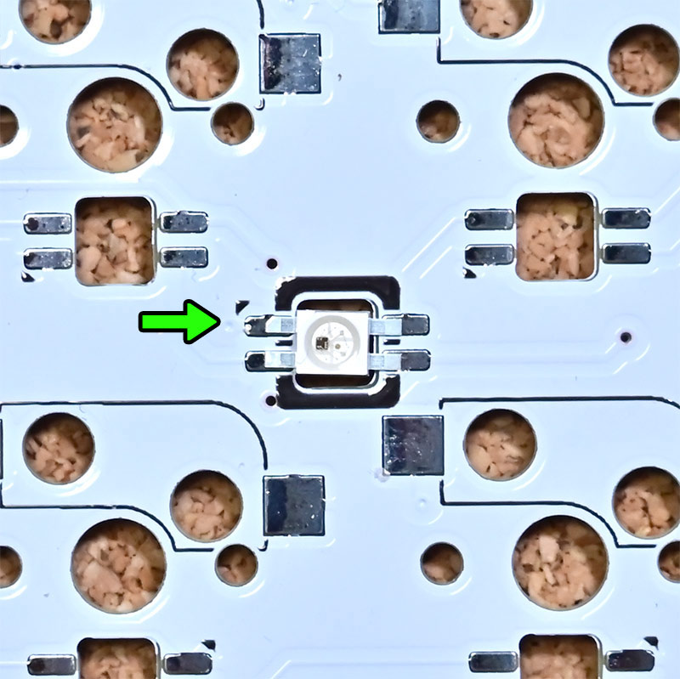
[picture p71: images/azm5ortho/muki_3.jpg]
    <td></td>
    <td valign="top">
      8ヶ所LEDの穴の枠が黒く塗られている所があり、こちらはLEDを表向きにしてはんだします。<br>
      こちらもPCBの三角マークと、LEDの足の角が欠けている方向を一緒にして下さい。<br><br>
    </td>
  </tr>
</table>

<br><br>

## スイッチ用PCBソケットのはんだ付け
<table>
  <tr>
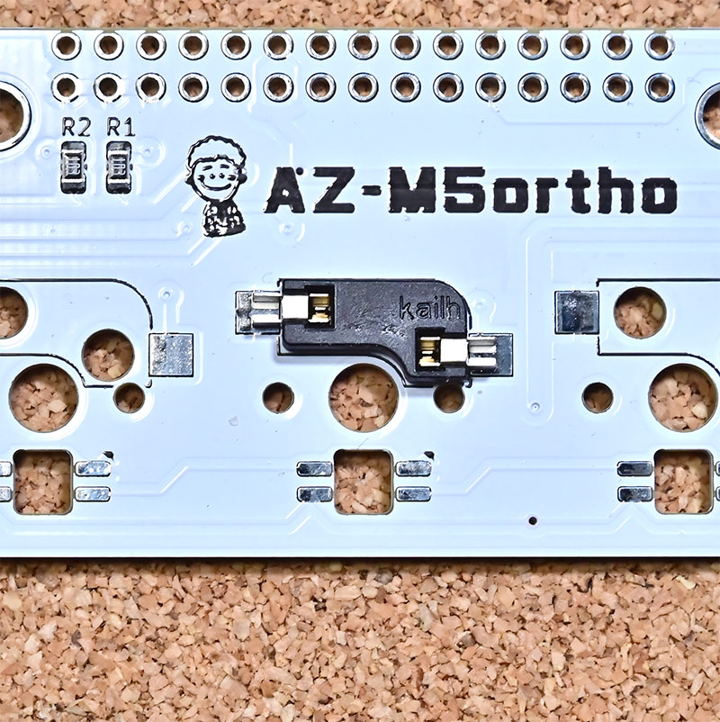
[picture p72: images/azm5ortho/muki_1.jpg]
    <td></td>
    <td valign="top">
      ソケット用の穴にソケットを差し込みはんだ付けします。
    </td>
  </tr>
</table>

<br><br>

## ピンヘッダのはんだ付け
<table>
  <tr>
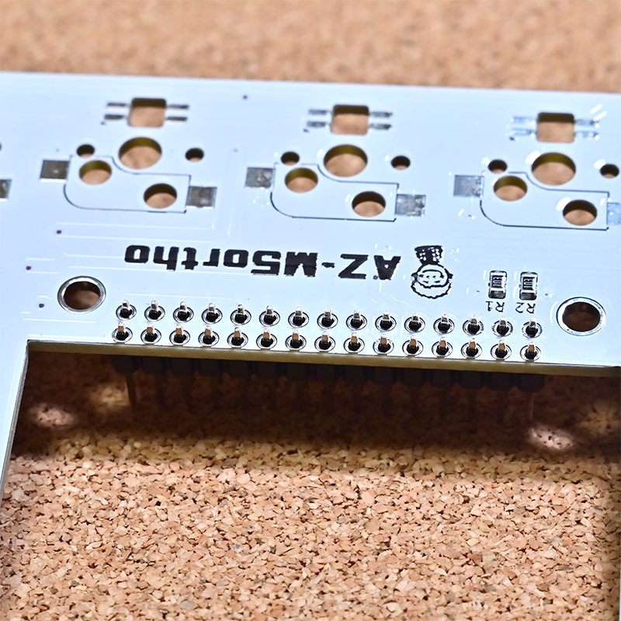
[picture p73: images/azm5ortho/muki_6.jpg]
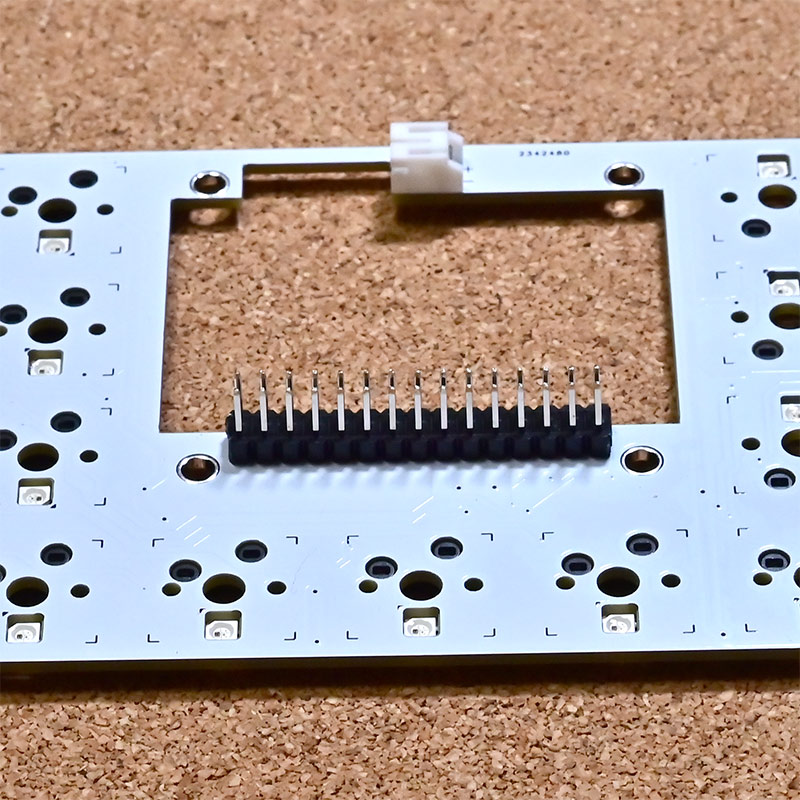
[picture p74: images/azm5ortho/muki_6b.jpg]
    <td><br></td>
    <td valign="top">
      ニッパーなどでピンヘッダを幅15ピンでカットし、PCBの表側から差し込み、裏側裏側をはんだ付けします。<br>
      ※ この位置が重要でピンヘッダが斜めに刺さっていたりズレたりするとM5StackCore2の位置がズレます。<br>
      ※ 心配な方はM5StackCore2にピンヘッダを差し込んだ状態ではんだ付けするとズレずにはんだ付けできます。
    </td>
  </tr>
</table>

<br><br>

## PHコネクタのはんだ付け
<table>
  <tr>
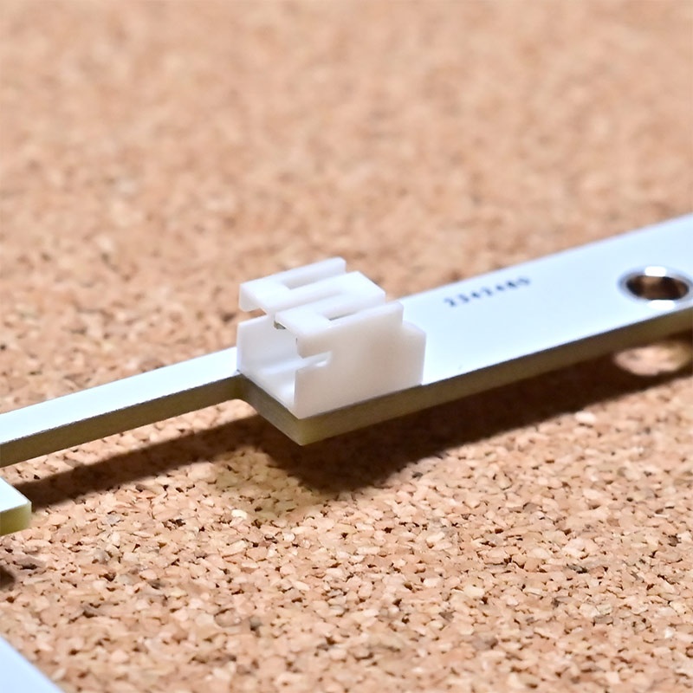
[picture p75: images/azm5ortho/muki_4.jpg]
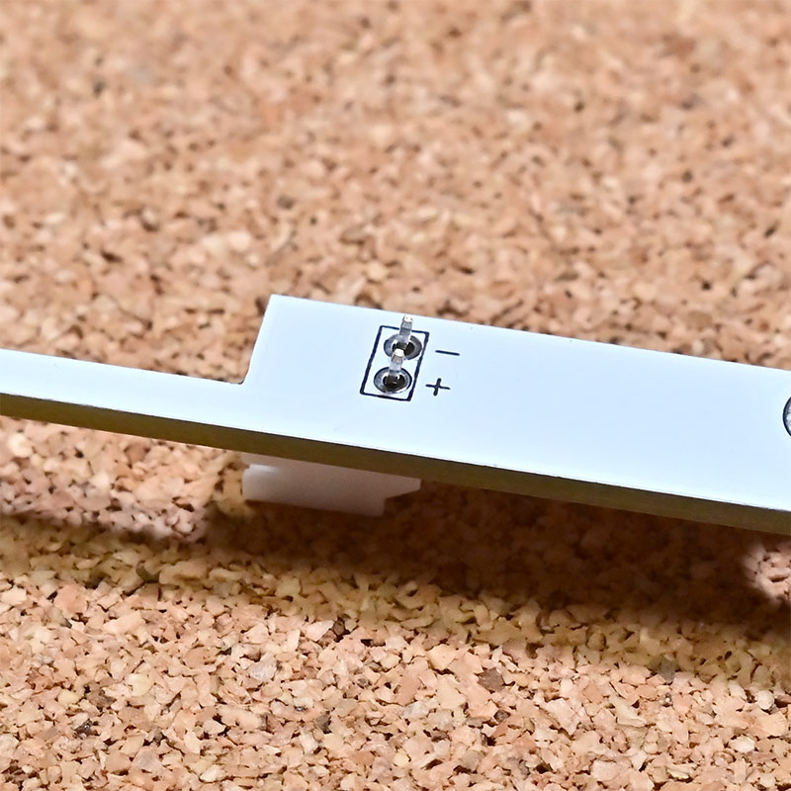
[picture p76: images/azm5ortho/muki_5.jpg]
    <td><br></td>
    <td valign="top">
      PHコネクタも表側から差し込み裏側をはんだ付けします。<br>
      ※ 誤って表裏逆にさすと＋、－が逆になってしまうので気を付けて下さい。
    </td>
  </tr>
</table>

<br><br>

## ねじ止め
<table>
  <tr>
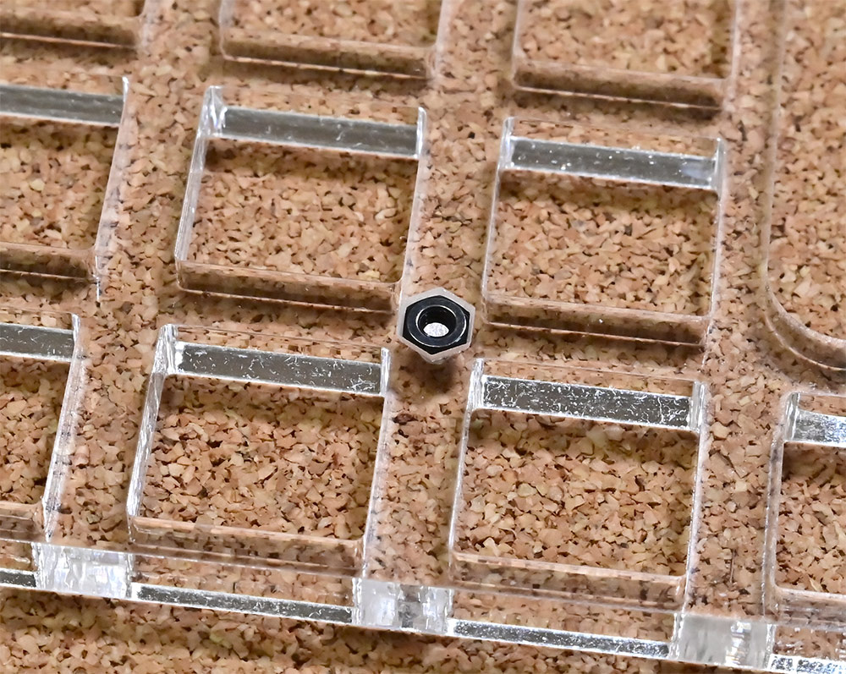
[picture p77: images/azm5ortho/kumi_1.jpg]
    <td></td>
    <td valign="top">
      まず各プレートの保護シートをはがします。<br>
      ※ ミドルプレートが割れやすいのでカッターなどを使用し少しずつはがして下さい。<br><br>
      その後トッププレートに六角ナット固定用の穴が開いているので、六角ナットを差し込みます。
    </td>
  </tr>
  <tr>
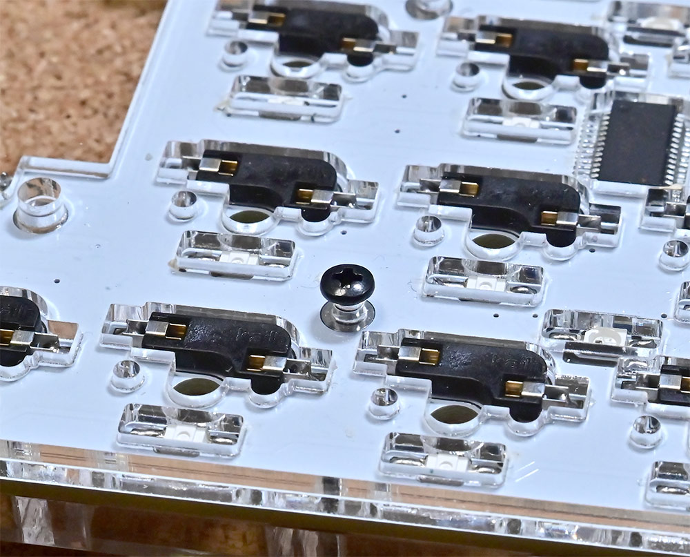
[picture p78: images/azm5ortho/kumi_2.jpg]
    <td></td>
    <td valign="top">
      トッププレート → PCB → ミドルプレート → ボトムプレート とはさみ、裏側からネジでとめます。
    </td>
  </tr>
  <tr>
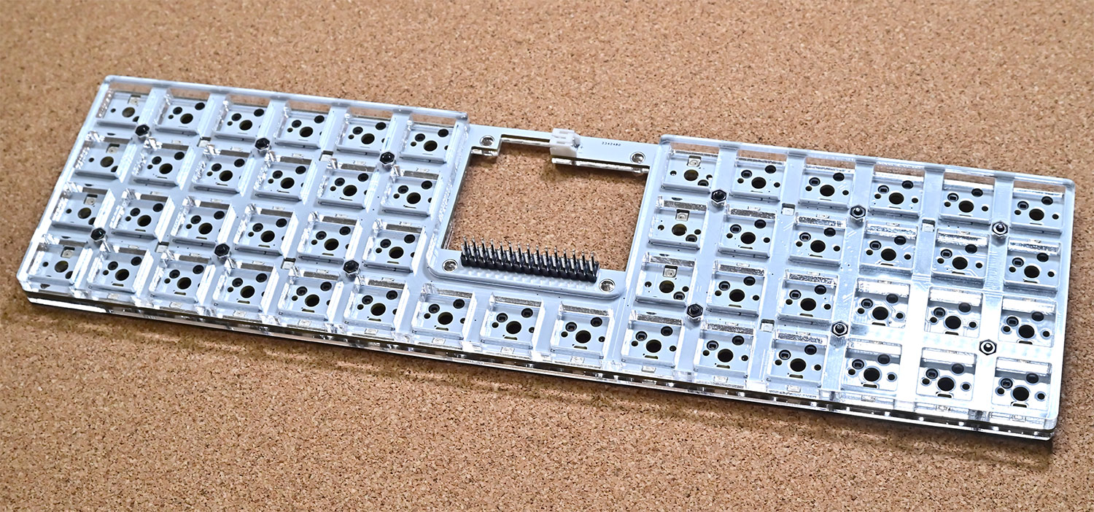
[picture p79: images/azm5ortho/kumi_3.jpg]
    <td></td>
    <td valign="top">
      左右6ヶ所ずつ、合計12ヶ所とめて下さい。
    </td>
  </tr>
</table>

<br><br>

## M5StackCore2 の取り付け
<table>
  <tr>
    <td></td>
    <td valign="top">
      M5StackCore2 の背面のコネクタ部分のフタを外します。<br>
      2か所穴が開いているのでそこへピンセット等を差し込みテコの原理で外します。
    </td>
  </tr>
  <tr>
    <td><br></td>
    <td valign="top">
      六角レンチで裏面4ヶ所のネジも外します。<br>
      外すとフタにバッテリーが両面テープで固定されているのでフタからバッテリーをはがして下さい。
    </td>
  </tr>
  <tr>
    <td></td>
    <td valign="top">
      M5StackCore2 のピンソケット部分に AZ-M5ortho のピンヘッダが刺さるように差し込み、裏面からネジどめします。<br>
      ネジは左側２つを短いネジ、右側２つを長いネジでとめます。
    </td>
  </tr>
</table>

<br><br>

これで組み立て完了です。<br>
後はキースイッチを差し込んで、キーキャップを取り付けて下さい。<br>
<br>

<br>

バッテリーは標準の物を紹介しましたが、PH2ピンのコネクタにささるリチウムバッテリに変更する事も可能です。<br>
変更する場合は400mAh以上の容量のバッテリーをご利用するのと、標準のバッテリーは抜いてご利用ください。<br>

<br>

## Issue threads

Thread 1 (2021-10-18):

Will there be an english build guide?

freznel10, 2021-10-18:
I just bought the kit from Yushakobo since it's so cool. Are there  plans for writing an English build guide?

palette-system, 2021-11-20:
We apologize for the delay in replying.
Due to lack of hands, the build guide is currently only in Japanese.
I am glad that overseas people are also interested in purchasing.

freznel10, 2021-11-20:
It is alright. I already purchased the kit and assembled it. I used google
translate to help me understand the instructions.

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

palette-system, 2021-11-20:
It was good that it seemed to be completed.
I would like to consider support in English in the future.
Thank you very much.

Closed 2021-11-20.

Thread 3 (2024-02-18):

M2Stack Core2 v1.1 Support

idiig, 2024-02-18:
Can M2Stack Core2 v1.1 function well for the keyboard?

https://www.switch-science.com/products/9349

palette-system, 2024-02-19:
It will probably work.
However, as we have not performed any operational tests, we cannot guarantee operation.

idiig, 2024-02-21:
Hi, thank you for your response.
I used the link https://azkey.jp/azm5ortho/ to install the firmware into the M2Stack.
But the device got frozen.

Then I tried the code in https://github.com/palette-system/az-m5ortho/tree/main/firmware/az_keyboard,
where I got an error which showed that `wirelib.h` was not in the path.

Do you have any suggestion?

PS:  files in https://github.com/palette-system/az-m5ortho/tree/main/firmware/lv_arduino was copied to the path.

palette-system, 2024-02-23:
Sorry, I'll try it myself when I have time.
The missing file may be here.

https://github.com/palette-system/az-core/blob/main/firmware/az_keyboard/src/lib/wirelib.h
https://github.com/palette-system/az-core/blob/main/firmware/az_keyboard/src/lib/wirelib.cpp

idiig, 2024-02-23:
Thank you for the confirmation! I have tried the sketch.
The installation succeeded and the monitor worked well.
But touching key switches seems not to have a reaction.

When I start up the device, the display showed:

```
...
Adafruit_MCP23X17
begin_i2c 0 32 NG
begin_i2c 1 32 NG
begin_i2c 2 32 NG
begin_i2c 3 32 NG
```

I think there could be because of power supply problems, or other compatibility issues.

Anyway, thank you for you attention!

palette-system, 2024-05-04:
https://github.com/palette-system/az-m5ortho/tree/main/firmware

palette-system, 2024-05-09:
I also confirmed that it doesn't work with the current sources.
Please wait while we fix it
I will fix it soon

palette-system, 2024-05-09:
@idiig

I found out the reason why I couldn't get the key input.
We apologize for the delay in identifying the cause.
The cause was that when I passed true to initialize I2C in the fourth parameter of M5.begin, the I2C initialization I had performed was not performed.
By setting this parameter to false, key input is now possible, so please check it out.

https://github.com/palette-system/az-m5ortho/commit/882e639ae41b1162f51e2697660d7b27da72a4b8

In addition, we plan to upload bin files compiled with the latest code to the repository in the near future.

idiig, 2024-05-13:
Thank you! I will try it out

Closed 2024-05-15.

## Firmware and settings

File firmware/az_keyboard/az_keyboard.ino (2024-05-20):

// 環境の作り方
// https://raspberrypi.mongonta.com/howto-start-m5stack-core2arduinoide/

#include "az_common.h"
#include "az_keyboard.h"
#include "az_setting.h"

// 起動モード
int boot_type;

// 共通クラス
AzCommon common_cls = AzCommon();

// キーボードモードクラス
AzKeyboard azkb = AzKeyboard();

// 設定モードクラス
AzSetting azstg = AzSetting();

// タッチパネル用定期処理
static void background_touch_loop(void* arg) {
  azkb.touch_loop_exec();
}


void setup() {
    int i, j, s;
    // 共通処理の初期化
    common_cls.common_start();
    // eepromからデータ読み込み
    common_cls.load_data();
    // 画面設定読み込み
    common_cls.moniterset_load();
    // BLE用 MACアドレス取得
    common_cls.blemac_load();
    // common_cls.delete_all();
    // キーボードが選択されていなければキーボード選択画面表示
    if (strlen(eep_data.keyboard_type) == 0) {
        // ディスプレイ初期化
        disp = new Display();
        disp->begin(1);
        disp->view_keyboard_setting(); // キーボード選択画面表示
        mouse_pad_status = -1;
        while (true) {
            disp->loop_exec(); // 表示用ループ処理
            common_cls.restart_loop(); // リスタート用ループ処理
        }
    }
    // File fp = SPIFFS.open(SETTING_JSON_PATH);
    // while (fp.available()) { Serial.write(fp.read()); }
    // fp.close();
    // 設定jsonの読み込み
    common_cls.load_setting_json();
    // ディスプレイ初期化
    disp = new Display();
    disp->begin(disp_rotation);
    // RGB_LEDクラス初期化
    if (rgb_pin > 0 && rgb_len > 0 && matrix_row > 0 && matrix_col > 0) {
        M5.Lcd.printf("RGB_LED: pin=%D len=%D row=%D col=%D\n", rgb_pin, rgb_len, matrix_row, matrix_col);
        rgb_led_cls.begin( rgb_pin, rgb_len, matrix_row, matrix_col, &select_layer_no, led_num, led_num_length, key_matrix, key_matrix_length);
        delay(100);
    }
    // サウンドクラス初期化
    sound_cls.begin();
    // キーの入力ピンの初期化
    common_cls.pin_setup();
    // 起動回数を読み込み
    common_cls.load_boot_count();
    // 打鍵数を自動保存するかどうかの設定を読み込み
    key_count_auto_save = 0;
    common_cls.load_file_data(KEY_COUNT_AUTO_SAVE_PATH, (uint8_t *)&key_count_auto_save, 1);
    // マウスパッド設定を読み込み
    common_cls.mouse_pad_load();
    // 起動モード取得
    ESP_LOGD(LOG_TAG, "boot_mode = %D\r\n", eep_data.boot_mode);
    boot_type = eep_data.boot_mode;
    // キーの状態を取得
    common_cls.key_read();
    // 今選択してるレイヤーをデフォルトに
    select_layer_no = default_layer_no;
    if (boot_type == 1) {
        ESP_LOGD(LOG_TAG, "設定モード起動\n");
        // 設定モード開始
        azstg.start_setting();
        // 次回起動時キーボード起動するようモード設定
        common_cls.set_boot_mode(0);

    } else {
        ESP_LOGD(LOG_TAG, "キーボードモード起動\n");
        // キーボードとして起動
        azkb.start_keyboard();
        // タッチパネル用バック処理
        xTaskCreatePinnedToCore(background_touch_loop, "tcloop", 2048, NULL, 20, NULL, 1);

    }
}


// ループ処理本体
void loop() {
    if (boot_type == 1) {
      // 設定モード用ループ
      azstg.loop_exec();

    } else {
      // キーボードモード用ループ
      azkb.loop_exec();
    }
}

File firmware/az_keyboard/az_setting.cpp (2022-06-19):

#include "Arduino.h"
#include <WiFi.h>
#include <WiFiClient.h>
#include <WebServer.h>
#include <Update.h>
#include <ESPmDNS.h>
#include <DNSServer.h>
#include "az_common.h"
#include "az_setting.h"

#include "src/html/index_bin.h"
#include "src/html/config_js_bin.h"
#include "src/html/index_js_bin.h"
#include "src/html/setting_menu_js_bin.h"



//無線LANのサーバー設定
const byte DNS_PORT = 53;
DNSServer dnsServer;
WebServer server(80);

// ファイルアップロードの戻り値用
char upload_buf[64];

// ファイルアップロードのステータス
int upload_stat;

// ファイルアップ用のファイルポインタ
File upfp;

// キーが押されたか
int last_key_down = -1;

// データ受け取り用のバッファ(受け取ったサイズ+データのポインタ)
int post_data_size;
uint8_t *post_data_buf;


// IP アドレスデータを表示用の文字列にする
String toStringIp(IPAddress ip) {
    String res = "";
    for (int i = 0; i < 3; i++) {
        res += String((ip >> (8 * i)) & 0xFF) + ".";
    }
    res += String(((ip >> 8 * 3)) & 0xFF);
    return res;
}


void captivePortal() {
    //無効リクエストはすべてESP32に向ける
    server.sendHeader("Location", "http://"+toStringIp(WiFi.softAPIP())+"/", true);
    server.send(302, "text/plain", "");
    server.client().stop();
}

bool handleUrl(String path) {
    char scmd[64];
    int i, n, r;
    path.toCharArray(scmd, 64);
    ESP_LOGD(LOG_TAG, "url path: %S", scmd);
    if (path.equals("/")){
        // メインページ
        server.send(200,"text/html", index_html_bin);
        return true;

    } else if (path.indexOf("/index.js") == 0) {
        // メインjs
        server.send(200,"text/js", index_min_js_bin);
        return true;

    } else if (path.indexOf("/config.js") == 0) {
        // メインjs
        server.send(200,"text/js", config_js_bin);
        return true;

    } else if (path.indexOf("/setting_menu.js") == 0) {
        // メインjs
        server.send(200,"text/js", setting_menu_min_js_bin);
        return true;

    } else if (path.indexOf("/firmware_version") == 0) {
        // ファームウェアのバージョン教えて
        sprintf(scmd, "{\"v\": \"%S\", \"d\": %D}", FIRMWARE_VERSION, disp_rotation);
        server.send(200,"text/html", scmd);
        return true;

    } else if (path.indexOf("/last_key_down") == 0) {
        // 最後に押されたキー教えて(キーの現在の設定も返す)
        sprintf(scmd, "%D", last_key_down);
        server.send(200,"text/plan", scmd);
        last_key_down = -1;
        return true;

    } else if (path.indexOf("/get_key_status") == 0) {
        // 現在のキーの入力状態を教えて
        for (i=0; i<key_input_length; i++) {
            if (common_cls.input_key[i]) {
                scmd[i] = '1';
            } else {
                scmd[i] = '0';
            }
        }
        scmd[i] = '\0';
        server.send(200,"text/plan", scmd);
        return true;

    } else if (path.indexOf("/key_length") == 0) {
        // キーの数教えて
        sprintf(scmd, "%D", key_input_length);
        server.send(200,"text/plan", scmd);
        return true;

    } else if (path.indexOf("/get_setting_json") == 0) {
        // 設定JSON教えて
        File json_file = SPIFFS.open(SETTING_JSON_PATH);
        server.streamFile(json_file, "text/json");
        json_file.close();
        return true;

    } else if (path.indexOf("/file_list") == 0) {
        // ファイルリストの取得
        File dirp = SPIFFS.open("/");
        File filep = dirp.openNextFile();
        String res = "{\"data\": [";
        while(filep){
            res += "\"" + String(filep.name()) + "\",";
            filep = dirp.openNextFile();
        }
        res += "\".\"]}";
        server.send(200,"text/plan", res.c_str());

    } else if (path.indexOf("/read_file_") == 0) {
        // 指定したファイルを読み込み ( /read_file_{ファイル名} でアクセス)
        // パスの後ろがファイル名
        String file_path = "/" + path.substring(11);
        // 読み込んで返す
        if(SPIFFS.exists(file_path)){
            File fp = SPIFFS.open(file_path, "r");
            server.streamFile(fp, "application/octet-stream");
            fp.close();
        } else {
            server.send(500,"text/plan", "file none");
        }
        return true;
        
    } else if (path.indexOf("/exists_file_") == 0) {
        // 指定したファイルの有無を0/1で返す ( /exists_file_{ファイル名} でアクセス)
        // パスの後ろがファイル名
        String file_path = "/" + path.substring(13);
        // 読み込んで返す
        if(SPIFFS.exists(file_path)){
            server.send(200,"text/plan", "1");
        } else {
            server.send(200,"text/plan", "0");
        }
        return true;
        
    } else if (path.indexOf("/delete_file_") == 0) {
        // 指定されたファイルを削除( /delete_file_{ファイル名} でアクセス)
        // パスの後ろがファイル名
        String file_path = "/" + path.substring(13);
        // 削除処理
        if(SPIFFS.exists(file_path)){
            if (!SPIFFS.remove(file_path)) {
                server.send(500,"text/plan", "file delete error");
                return true;
            }
        }
        server.send(200,"text/plan", "OK");
        return true;
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

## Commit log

2021-09-19 wire change
2021-09-25 add led setting
2021-10-06 simple sample
2021-11-20 Update az_keyboard.cpp
    マウスパッドモードで感度１００にして、タッチパネルをすばやくスワイプすると逆方向に動くことがあります。
    おそらく、bleKeyboard.mouse_move関数の引数がsigned charのため、int→singed charに変換する際、数値が変わってしまっているのではないでしょうか？-128～127の範囲にクリッピングしてから送る必要があると思います。
2022-02-20 add game sample
2022-02-21 edit led
2022-02-23 edit game sample
2022-03-05 add power
2022-03-12 add plate data
2022-04-14 add i2c option
2022-04-16 add i2c option read
2022-05-12 add mouse wheel
2022-07-02 update i2cread
2022-08-14 add i2c_rotary
2022-08-16 i2c option bug
2024-05-04 arduino version up
2024-05-08 led update
2024-05-15 add hardware
    [az-m5ortho.kicad_pcb]
2024-05-15 move hardware
    [az-m5ortho.kicad_pcb]
2024-05-15 add hardware emugotch
    [az-emugotch.kicad_pcb]
